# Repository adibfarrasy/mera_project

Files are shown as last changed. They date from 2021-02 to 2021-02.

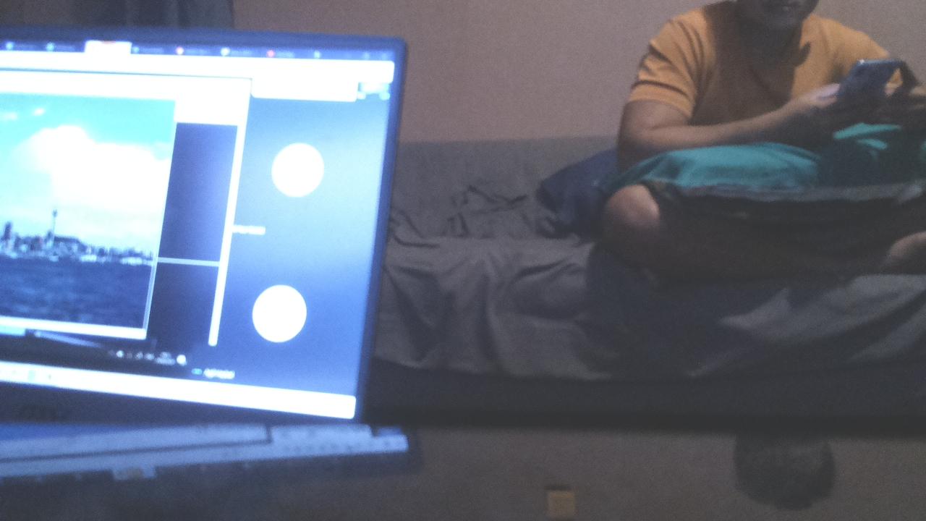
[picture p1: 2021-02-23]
device_firmware/temp_img.jpg

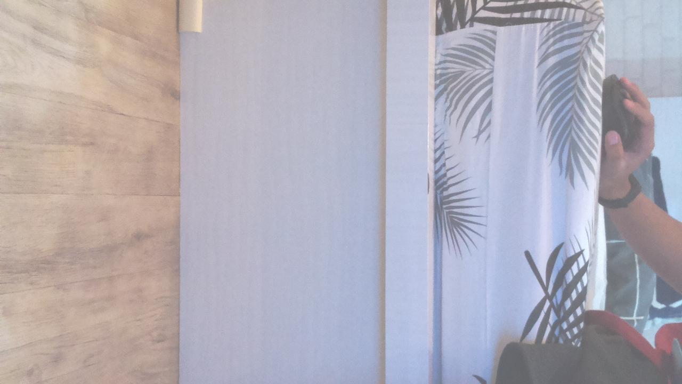
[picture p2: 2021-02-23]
device_firmware/state_of_the_art/temp_img.jpg

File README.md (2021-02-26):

# Mera Project #
My startup documentations. Project initiated in July 2020.

## My Role ##
- Mechanical Designer
- Electrical Designer
- Software Engineer
- Test Engineer
- Manufacturing Engineer
- Product Owner

## My Key Contributions ##
- Project Management
- Concept & Feature Generation
- Bill of Materials
- Scalable Hardware Design
- Scalable Firmware Design
- Prototyping & Testing
- Operations Planning
- QC Planning

## Project Summary ##
Mera planned to use Raspberry Pi SBC to enable KPI-tracking Digital Out Of Home (DOOH) media players e.g. media reach, media impression, audience gender, etc.\
The computer vision feature is deployed in an AWS, and the device serves to send video and camera metadata to the AWS database to be inferred by the deployed model.

## What's Inside ##
- `device_firmwares` directory contains the device codes that I developed for the Mera device.\
- `project_management` directory contains documents in the first few stages of the product lifecycle e.g. product requirements, Bill of Materials, FMEA, etc.\
- `operations_management` directory contains miscellaneous documents for startup operation purposes

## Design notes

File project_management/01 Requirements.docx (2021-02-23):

## MERA Lift Requirements

### SHALL - Commercial Claims

Note: these requirements exist to satisfy the needs of our clients, and to be used for our product's advertisement.

It is strongly preferred for these requirements to have objective quantitative measures such that they can hold up in court as a compelling evidence. As a start, all the requirements will be validated by in-house testing.

AI shall determine people’s gender with acceptable accuracy.

Min. spec: 85.0%

Max. spec: 99.7%

Validation plan: Test Plan LCC-01: Gender Classification

Validation result: Test Report LCC-01: Gender Classification

Target validated: Q3 2020

AI shall determine ads Reach with acceptable accuracy.

Min spec: 85.0%

Max. spec: 99.7%

Validation plan: Test Plan LCC-02: Reach Classification

Validation result: Test Report LCC-02: Reach Classification

Target validated: Q3 2020

AI shall determine ads Impression with acceptable accuracy.

Min spec: 85.0%

Max. spec: 99.7%

Validation plan: Test Plan LCC-03: Impression Classification

Validation result: Test Report LCC-03: Impression Classification

Target validated: Q3 2020

AI shall determine people’s age with acceptable accuracy.

Min spec: 85.0%

Max. spec: 99.7%

Validation plan: Test Plan LCC-04: Age Classification

Validation result: Test Report LCC-04: Age Classification

Target validated: Q3 2020

Device shall update to server frequently.

Min spec: 1 update/hour

Max. spec: 1 update/minute

Validation plan: Test Plan LCC-05: Connection Reliability

Validation result: Test Report LCC-05: Connection Reliability

Target validated: Q3 2020

Device shall detect which advertisement is displayed with acceptable accuracy.

Min spec: 95.0%

Max. spec: 99.7%

Validation plan: Test Plan LCC-06: Advertisement Detection

Validation result: Test Report LCC-06: Advertisement Detection

Target validated: Q3 2020

Device shall be secure in handling data.

Min spec: NA

Max. spec: NA

Validation plan: Data Ethics Guideline

Validation result: Peer Review with Core Mera Team

Target validated: Q3 2020

Device shall have a long runtime.

Min spec: 2160 hours of continuous operation

Max. spec: 9999 hours of continuous operation (outliers to be force-retired)

Validation plan: Test Plan LCC-07: Device Life

Validation result: Test Report LCC-07: Device Life

Target validated: Q3 2020

### MUST - User Safety and Comfort

Note: these requirements exist to protect all relevant stakeholders involved in the operation of the tangible aspect of our product.

It is strongly preferred for these requirements to have objective quantitative measures such that they can hold up in court as a compelling evidence. As a start, all the requirements will be validated by in-house testing.

Device must be quiet.

Min spec: 0dB at 1m distance

Max. spec: 62dB at 1m distance (-10dB from ambient noise)

Validation plan: Test Plan LUC-01: Device Acoustics

Validation result: Test Report LUC-01: Device Acoustics

Target validated: Q3 2020

Device electronics must not emit excess heat.

Min spec: 25 degrees Celsius @24 hr operation time

Max. spec: 80 degrees Celsius @24 hr operation time

Validation plan: Test Plan LUC-02: Device Temperature

Validation result: Test Report LUC-02: Device Temperature

Target validated: Q3 2020

Device must not emit toxic materials.

Min spec: NA

Max. spec: NA

Validation plan: Material Database

Validation result: Peer Review with Core Mera Team

Target validated: Q3 2020

Device must have abnormal case detections and shutdown procedures.

Min spec: NA

Max. spec: NA

Validation plan: Disruption Handling Database

Validation result: Peer Review with Core Mera Team

Target validated: Q4 2020

Device must be electrically insulated.

Min spec: -

Max. spec: no leakage

Validation plan: Test Plan LUC-03: Device Electrical Insulation

Validation result: Test Report LUC-03: Device Electrical Insulation

Target validated: Q4 2020

Device must be firmly mounted on the wall.

Min spec: 20N (approx. 10x device weight)

Max. spec: -

Validation plan: Test Plan LUC-04: Device Mounting

Validation result: Test Report LUC-04: Device Mounting

Target validated: Q4 2020

### SHOULD - Design Excellence

Note: these requirements exist to ensure we deliver the best product in the market, and to ensure a pleasant product experience to the relevant stakeholders in the fabrication, shipment, storage, installation, operation, and disposal of the tangible aspect of our product.

Dashboard should update frequently.

Min spec: 1 update/hour

Max. spec: 1 update/minute

Validation plan: Test Plan LDE-01: Dashboard Responsiveness

Validation result: Test Report LDE-01: Dashboard Responsiveness

Target validated: Q4 2020

Device should be aesthetically pleasing.

Min spec: NA

Max. spec: NA

Validation plan: Product Design Guideline

Validation result: Peer Review with Core Mera Team

Target validated: Q4 2020

Device should clearly show Mera brand.

Min spec: NA

Max. spec: NA

Validation plan: Product Design Guideline

Validation result: Peer Review with Core Mera Team

Target validated: Q4 2020

Device should be resilient to tampering.

Min spec: NA

Max. spec: NA

Validation plan: Product Design Guideline

Validation result: Peer Review with Core Mera Team

Target validated: Q4 2020

Device should be minimalistic.

Min spec: NA

Max. spec: NA

Validation plan: Product Design Guideline

Validation result: Peer Review with Core Mera Team

Target validated: Q4 2020

Device should be operable in dynamic light conditions.

Min spec: 100 Lux

Max. spec: 10,000 Lux

Validation plan: Test Plan LDE-02: Camera Sensitivity

Validation result: Test Report LDE-02: Camera Sensitivity

Target validated: Q4 2020

AI should determine stay duration of people in the lift with acceptable accuracy.

Min spec: 85.0%

Max. spec: 99.7%

Validation plan: Test Plan LDE-03: Duration Detection

Validation result: Test Report LDE-03: Duration Detection

Target validated: Q4 2020

Device should be serviceable.

Min spec: NA

Max. spec: NA

Validation plan: Technical Work Instruction

Validation result: Peer Review with Core Mera Team

Target validated: Q4 2020

Dashboard should be aesthetically pleasing.

Min spec: NA

Max. spec: NA

Validation plan: Product Design Guideline

Validation result: Peer Review with Core Mera Team

Target validated: Q4 2020

Dashboard should clearly show Mera brand.

Min spec: NA

Max. spec: NA

Validation plan: Product Design Guideline

Validation result: Peer Review with Core Mera Team

Target validated: Q4 2020

Dashboard should be minimalistic.

Min spec: NA

Max. spec: NA

Validation plan: Product Design Guideline

Validation result: Peer Review with Core Mera Team

Target validated: Q4 2020

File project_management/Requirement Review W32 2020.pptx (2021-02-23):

## Requirement Review

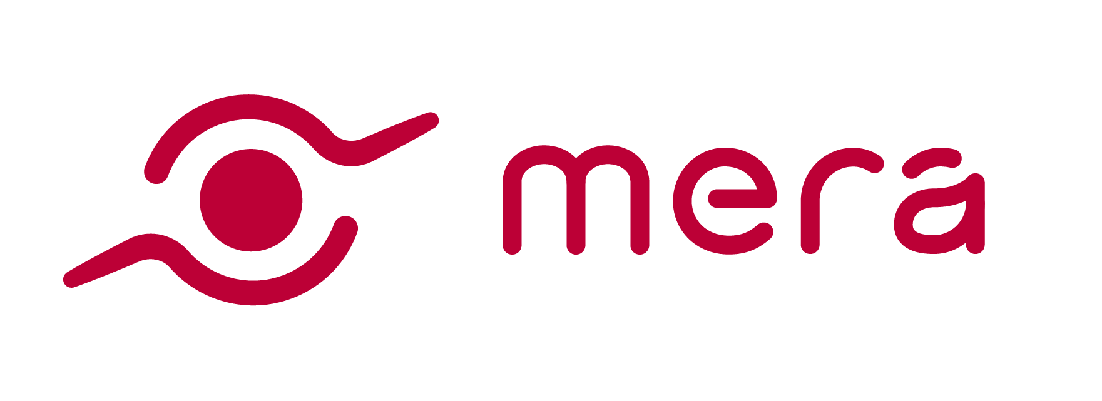
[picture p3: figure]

Author: Adib Farrasy
Date: 08/08/2020

Where we are

SHALL

MUST

SHOULD

0%

0%

0%

completion

completion

completion

Q3 2020 Target: 0%

Q3 2020 Target: 100%

Q3 2020 Target: 50%

## Requirement Review

Agenda #1
Requirement Name: Product should be minimalistic

Agenda #2
Requirement Name: Product should be aesthetically pleasing

Agenda #3
Requirement Name: Product should clearly show Mera brand

## Peer Review

Product should be minimalistic.

Agenda #1

Primary view/ Facade:

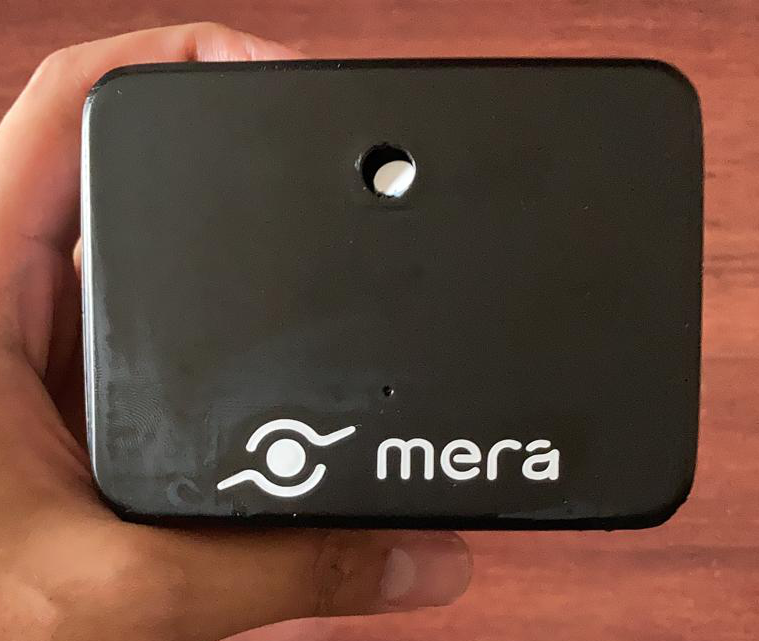
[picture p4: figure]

Result | PASS/ ALLOW / FAIL
Test Resolution | Full Product
Core Team Signoff | <Hilmy/ Agil/ Fatchur>

Secondary views:

Tertiary views:

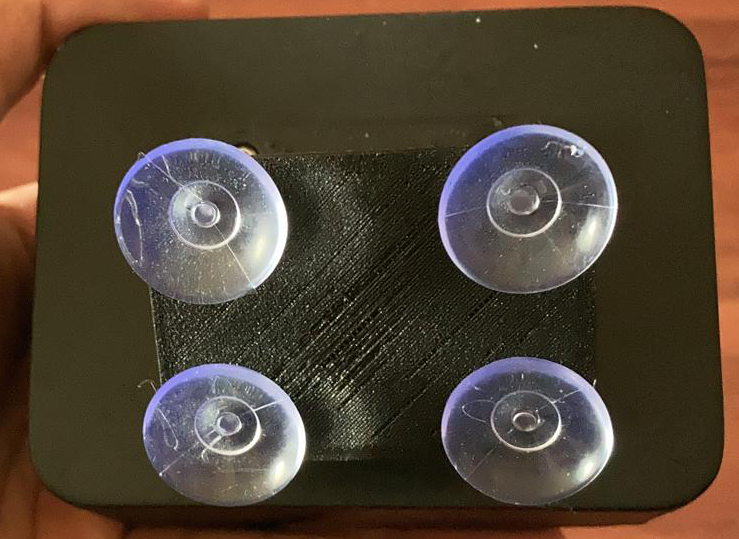
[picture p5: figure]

mounts

Back

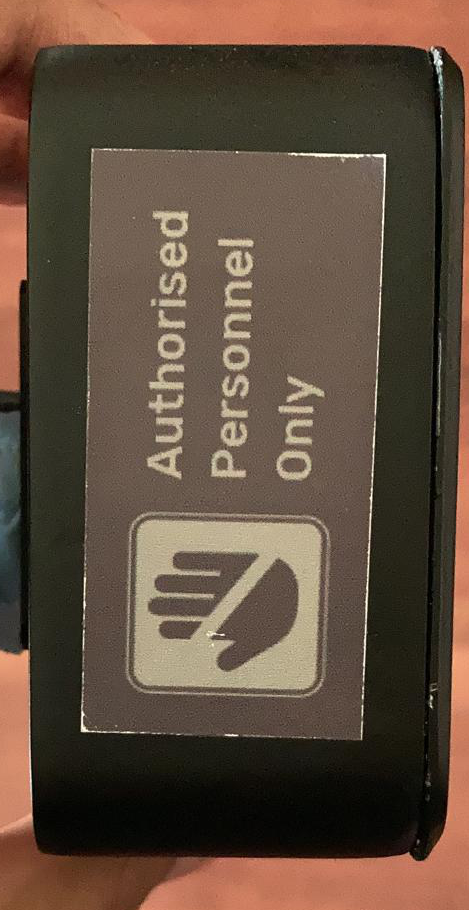
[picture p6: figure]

sticker

Right

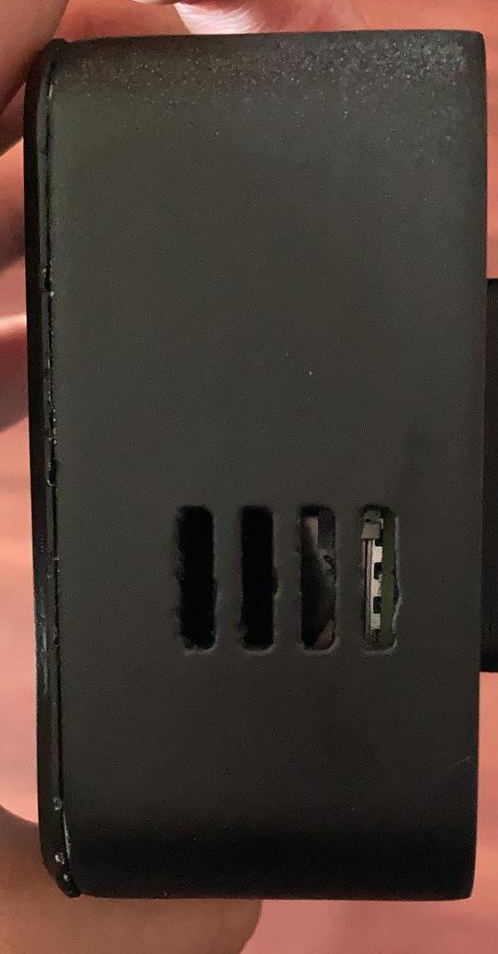
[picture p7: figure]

vent holes

Left

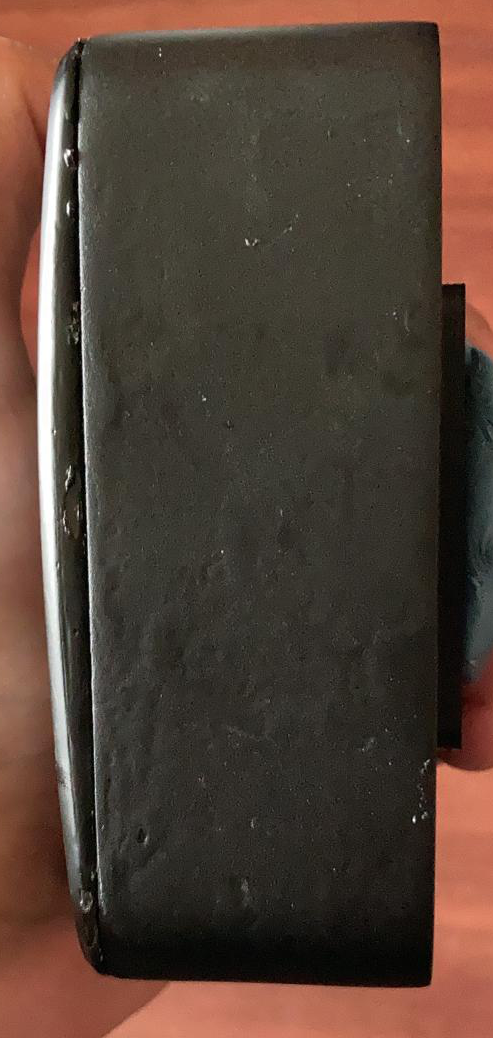
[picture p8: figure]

Bottom

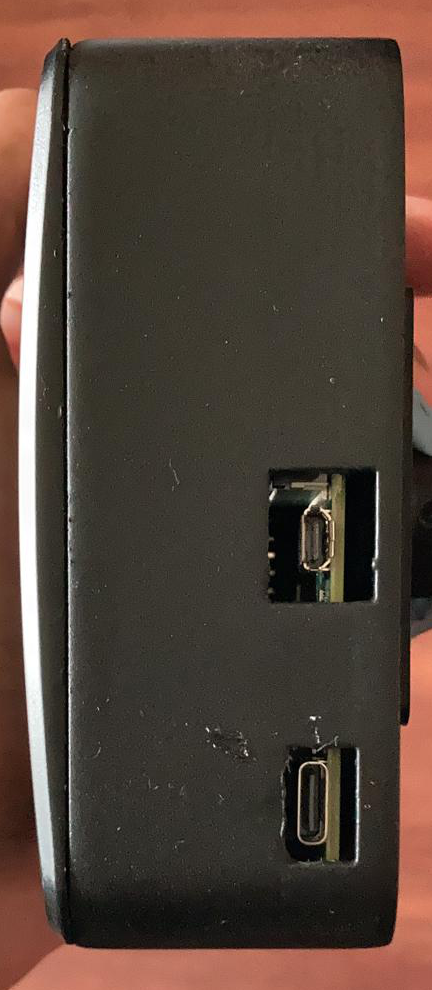
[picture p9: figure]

Cable holes

Top

camera

Indicator light

logo

NEED SIGNOFF
- Quality OK?
- Features OK?
- Minimalism achieved?

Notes: Agil: all OK, need validation of suction cup strength
Hilmy: all OK, change sticker color
Fatchur: all OK

## Peer Review

Product should be aesthetically pleasing.

Agenda #2

Primary view/ Facade:

Device footprint:
100mm x 75mm
40mm thk without mounts, ~88mm thk with mounts.

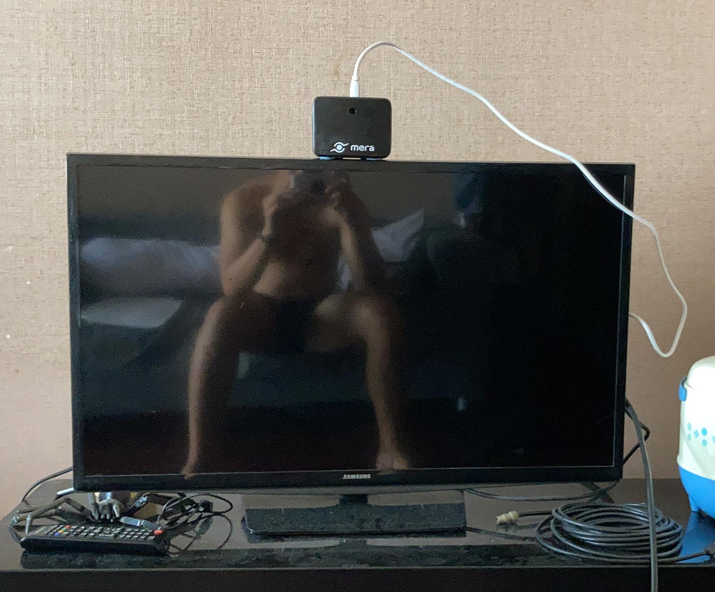
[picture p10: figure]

4.9”

32”

Result | PASS/ ALLOW / FAIL
Test Resolution | Full Product
Core Team Signoff | <Hilmy/ Agil/ Fatchur>

NEED SIGNOFF
- Device size OK?
- Device position OK?
- Visible wires OK?

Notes: Hilmy: size OK, position ALLOW: prefer higher position, visible wires NOT OK
Agil: size OK, position OK, visible wires NOT OK
Fatchur: size OK, positon OK, visible wires NOT OK

TRY L-shaped cable facing back, black color

## Peer Review

Product should clearly show Mera brand.

Agenda #3

Unresized photos:
Taken at eye level, angle adjusted to show device

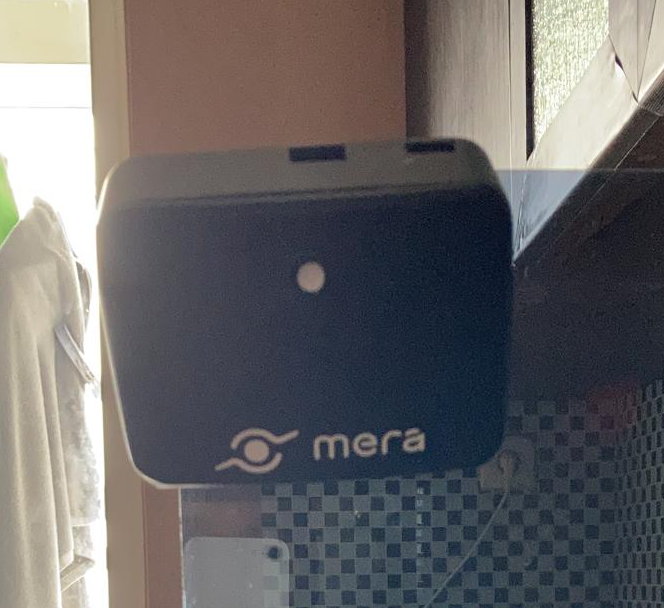
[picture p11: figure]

Device @ eye level

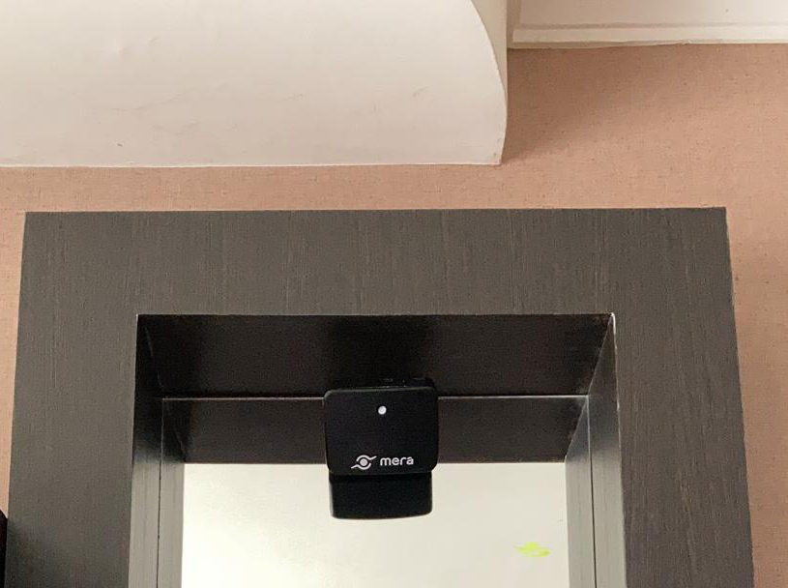
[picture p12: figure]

Device @ ~2.5m height

NEED SIGNOFF
- Logo visibility OK?
- Brand name visibility OK?

Result | PASS/ ALLOW / FAIL
Test Resolution | Full Product
Core Team Signoff | <Hilmy/ Agil/ Fatchur>

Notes: Hilmy: visibility OK, name OK
Agil: visibility OK, name OK
Fatchur: visibility OK, name OK

## Alternative Approach

RISK: Current design may not be aesthetically pleasing.
Addressing wires: use Bluetooth HDMI.
Addressing size: use Pi Zero W (DESIGN OVERHAUL)
Addressing position:
mount to the side nearest to the HDMI port (if using cable)
mount further up to be more discreet?

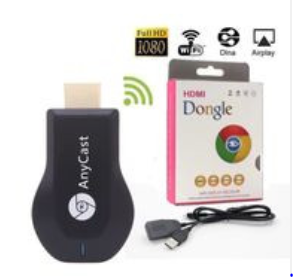
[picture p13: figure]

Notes: Bluetooth HDMI: Compatibility issue? Reliability issue?

## Alternative Approach

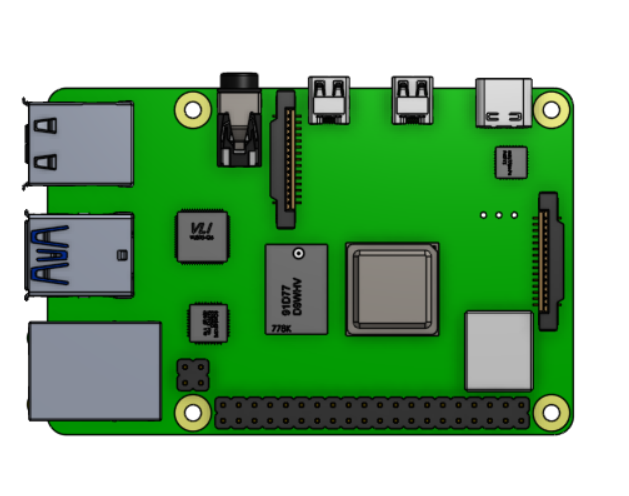
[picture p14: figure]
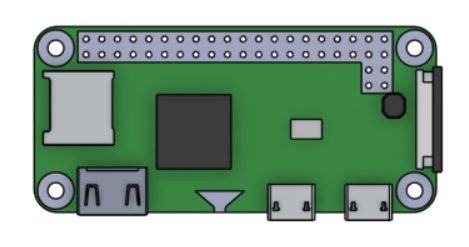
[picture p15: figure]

| Pi Zero W | Pi 4B 2GB
Dimension | 66.0mm x 30.5mm x 5.0mm | 85.6mm × 56.5mm x 18.6mm
Processor | 1.0GHz, single core | 1.5GHz, quad core
RAM | 1GB | 2GB
Cost | US$10 (Rp172.000)/ Rp370.000 Tokopedia | US$35 (Rp520.000)/ Rp 710.000 Tokopedia

## Mera Lift Pi Zero Preview

Primary view/ Facade:

Device footprint:
130*mm x 35mm
40mm thk without mounts, ~88mm thk with mounts.
*length can be shortened up to 80mm

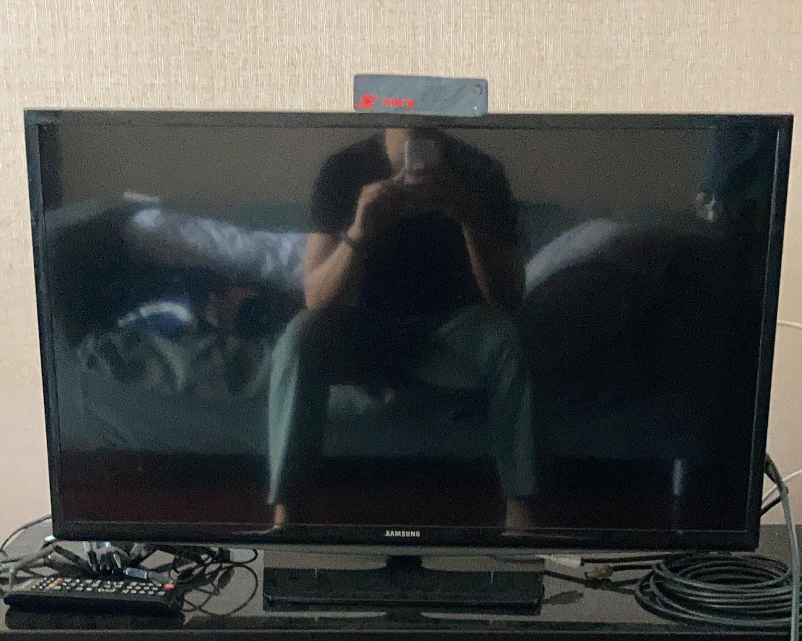
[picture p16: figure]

Orientation Option A
Top of TV
MUST use BT-HDMI

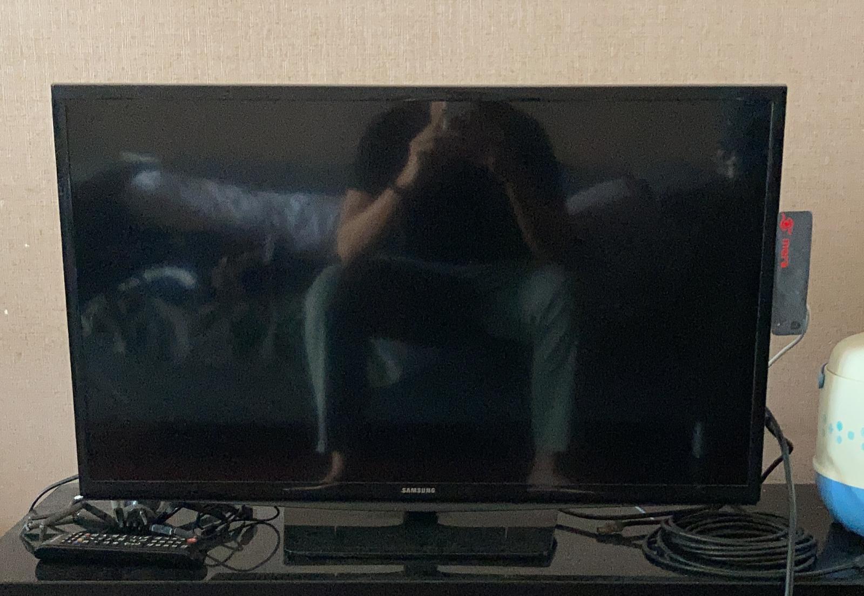
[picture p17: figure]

5.3”

Orientation Option B
Side of TV (nearest to HDMI port)
Don’t need BT-HDMI

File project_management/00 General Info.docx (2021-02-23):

# MERA Lift

MERA Lift project does not include the TV to display the ad. Display devices required will be provided by the contractor, but the video player will be connected to the MERA Lift device for data collection.

Product Visual

### MERA Lift - Isometric View

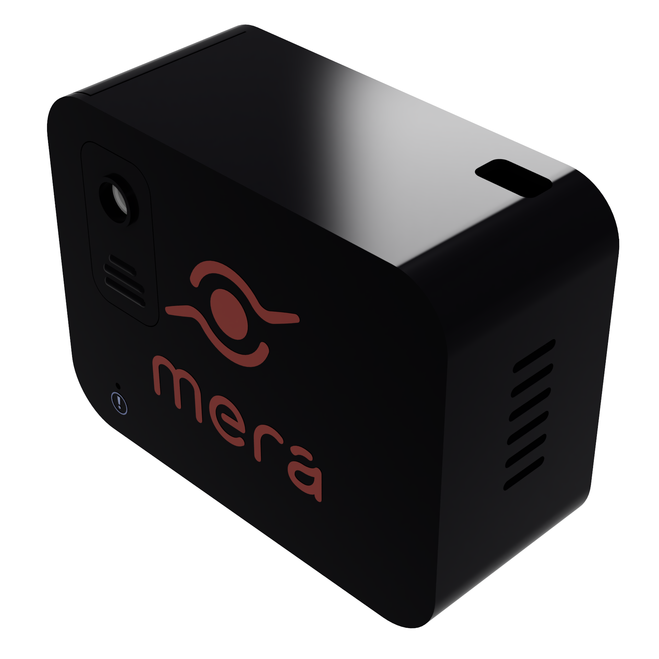
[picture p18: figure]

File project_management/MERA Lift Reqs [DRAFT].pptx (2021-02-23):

## MERA Lift

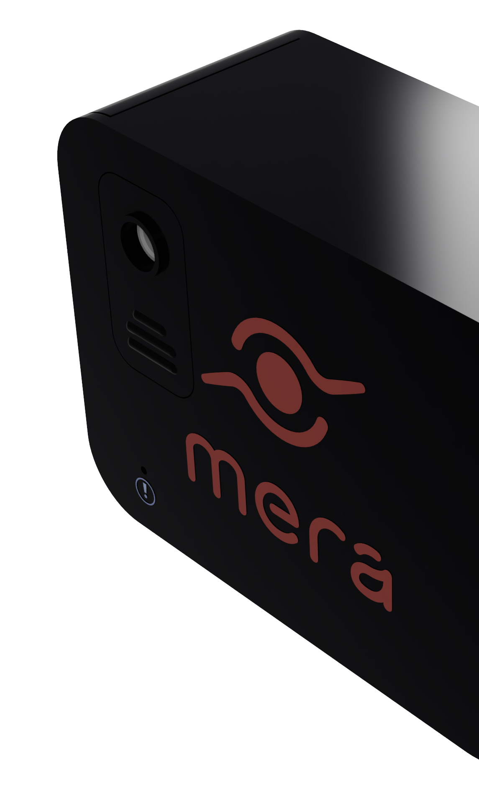
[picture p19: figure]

Requirements

## Commercial Claims

SHALL - Commercial Claims
Product shall determine people’s gender with acceptable accuracy | Product shall update to dashboard frequently | Dashboard shall display Reach based on time and place
Product shall determine ads Reach with acceptable accuracy | Product shall detect which advertisement is displayed | Dashboard shall display Impression based on time and place
Product shall determine ads Impression with acceptable accuracy | Product shall be secure in handling data | Dashboard shall display gender based on time and place
Product shall determine people’s age with acceptable accuracy | Product shall have long run time | Dashboard shall display age based on time and place

## User Safety and Comfort

MUST - User Safety and Comfort
MERA Lift - Product must be quiet in normal and abnormal operations | Product must have abnormal case detections and abnormal shutdown procedure | Product must be electrically insulated in normal and abnormal operations
Product must not emit excess heat in normal and abnormal operations | Data collected must be honestly disclosed with regards to its use | Product must be firmly mounted on the lift wall
Product must not emit toxic materials in normal and abnormal operations | Product must be environmentally friendly

## Design Excellence

SHOULD - Design Excellence
Product should update to server frequently | Dashboard should be aesthetically pleasing | Product should determine stay duration of people in the lift with acceptable accuracy
Product should be aesthetically pleasing | Product design should be minimalistic | Product should be serviceable
Product should clearly show MERA brand | Product device status should be monitored in the dashboard | Dashboard design should be minimalistic
Product should be resilient to lay people tampering | Product should be operable in natural light conditions | Dashboard should be visually displayed in graphs

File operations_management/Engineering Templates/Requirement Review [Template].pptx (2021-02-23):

## Requirement Review


Author: John Doe
Date: DD/MM/YYYY

Where we are

SHALL

MUST

SHOULD

0%

0%

0%

completion

completion

completion

Q3 2020 Target: 0%

Q3 2020 Target: 100%

Q3 2020 Target: 50%

## Requirement Review

Author: John Doe
Date: DD/MM/YYYY

Agenda #1
Requirement Name: Product shall/must/should

Agenda #2
Requirement Name: Product shall/must/should

Agenda #N
Requirement Name: Product shall/must/should...

## Verification Process

Agenda #N

For full document, refer to test report XX-XX
Summarize relevant data here, taken from Test Report.

Result | PASS/ ALLOW / FAIL
Test Resolution | <Part/ Assembly/ Modular/ Full Product>
Core Team Signoff | <Hilmy/ Agil/ Adib>

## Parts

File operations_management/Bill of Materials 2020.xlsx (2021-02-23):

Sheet: Equipment
No | Date | Item | Price | Cur | Qty | Shipping Cost | Total Cost (kIDR) | Rationale | Grand Total (in kIDR)
1 | 2020-05-07 | 3D printer | 787.36 | SGD | 1 | 0 | 8228 | for case prototyping | 8,810.90
2 | 2020-12-07 | soldering kit | 198 | kIDR | 1 | 0 | 198 | for electronics prototyping
3 | 2020-12-07 | caliper | 50 | kIDR | 1 | 0 | 50 | for quality check
4 | 2020-12-07 | glass bed | 149 | kIDR | 1 | 0 | 149 | for case prototyping
5 | 13/7/2020 | blue tack | 21 | kIDR | 1 | 0 | 21 | for case prototyping
6 | 21/7/2020 | M2.5 screws | 1.1 | kIDR | 50 | 0.7 | 55.7 | for case prototyping
7 | 21/7/2020 | super glue | 50 | kIDR | 1 | 10 | 60 | for case prototyping
8 | 21/7/2020 | solder lead | 11.2 | kIDR | 1 | 9 | 20.2 | for electronics prototyping
9 | 21/7/2020 | 5050 LED | 1.4 | kIDR | 10 | 15 | 29 | for electronics prototyping
10 | 29/7/2020 | Amplas Assorted Grits | 2.5 | kIDR | 4 | 5.1 | 15.1 | for case prototyping
11 | 2020-08-08 | Anycast HDMI Dongle | 67.5 | kIDR | 1 | 10 | 77.5 | for electronics prototyping
12 | 2020-04-08 | Cooling Fan 5V 3010 | 62 | kIDR | 1 | 9 | 71 | for electronics prototyping
13 | 13/8/2020 | Dempul Kayu Propan | 28.5 | kIDR | 1 | 9 | 37.5 | for case prototyping
14 | 2020-09-08 | Heatsink Aluminum 8x8x5 | 1.9 | kIDR | 1 | 8.6 | 10.5 | for electronics prototyping
15 | 13/8/2020 | Kabel HDMI to Mini HDMI | 50 | kIDR | 1 | 5 | 55 | for electronics prototyping
16 | 17/8/2020 | Mur M2.5 | 0.4 | kIDR | 50 | 10 | 30 | for electronics prototyping
17 | 2020-11-08 | Raspberry Pi Zero W | 2 | kIDR | 375 | 41.768 | 791.768 | for electronics prototyping
18 | 16/8/2020 | RPi Zero Camera 5MP | 217 | kIDR | 1 | 10 | 227 | for electronics prototyping
19 | 16/8/2020 | SanDisk Ultra MicroSD 32GB | 85.8 | kIDR | 2 | 18 | 189.6 | for electronics prototyping

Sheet: MERA Lift Q3 2020
No | Date | Item | Price | Cur | Qty | Total Cost (kIDR) | Rationale | Grand Total (in kIDR)
1 | 15/6/2020 | Raspberry pi 4B 8GB | 119.99 | SGD | 1 | 1253.8955 | SBC for Adib's protoyping | 5577.15
2 | 15/6/2020 | Micro HDMI to HDMI adapter | 10.71 | SGD | 1 | 111.9195 | Adapter for Adib's protoyping
3 | 15/6/2020 | 15W USB-C UK power plug | 12.50 | SGD | 1 | 130.625 | power plug for Adib's protoyping
4 | 15/6/2020 | 16GB Micro SD Card | 12.86 | SGD | 1 | 134.387 | hard disk for Adib's protoyping
5 | 15/6/2020 | Raspberry pi 4B case | 8.93 | SGD | 1 | 93.3185 | case for Adib's prototyping
6 | 2020-05-05 | Wi-Fi Wireless adapter | 42.00 | kIDR | 1 | 42 | for Fatchur's protoyping
7 | 2020-05-05 | Raspi Camera Module v2 | 439.00 | kIDR | 1 | 439 | for Fatchur's protoyping
8 | 2020-05-05 | Raspberry pi 4B 4GB full kit | 1304.00 | kIDR | 1 | 1304 | for Fatchur's protoyping
9 | 2020-05-05 | Nvidia Jetson Nano Devkit | 2068.00 | kIDR | 1 | 2068 | for Fatchur's protoyping

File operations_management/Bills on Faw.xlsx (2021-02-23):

Date | Item | Price | Qty | Shipping | Total Cost | Rationale | Grand Total (in kIDR)
2020-07-11 | 3d Filament Silk Black Gray 1 kg (https://www.tokopedia.com/xyzgarage/3d-filament-silk-black-gray-1-kg) | 230000 | 1 | 11000 | 241000 | 3d printer filament | 1.724.750,00
2020-07-14 | Studio Mini Box | 41000 | 1 | 5500 | 46500 | product showcasing
2020-07-14 | Rotating Display | 25000 | 1 | 10000 | 35000 | product showcasing
2020-07-14 | Knife Pen | 23500 | 1 | 5500 | 29000 | general purpose
2020-07-14 | Print UV Decal sticker | 130000 | 1 | 0 | 130000 | trying out sticker materials. failed.
2020-07-20 | Cutting Sticker V&J | 20000 | 1 | 13000 | 33000 | cutting sticker for device visual. success.
2020-07-23 | Bahan Filament PLA Printer 3D aneka pilihan warna (https://www.tokopedia.com/voltapro49/bahan-filament-pla-printer-3d-aneka-pilihan-warna) | 186000 | 1 | 15900 | 201900 | new 3d filament supplier
2020-07-26 | Ditton Spray paint | 20000 | 3 | 5500 | 65500 | device coloring
2020-08-01 | Paper Corner-rounder | 49900 | 1 | 5500 | 55400 | general purpose
2020-08-01 | Nail drill grinder | 58800 | 1 | 0 | 58800 | for polishing device
2020-08-03 | Ditton Spray paint | 21000 | 3 | 0 | 63000 | device coloring
2020-08-07 | Lem Rajawali | 15000 | 1 | 5000 | 20000 | for polishing device
2020-08-07 | Bahan Filament PLA Printer 3D aneka pilihan warna (https://www.tokopedia.com/voltapro49/bahan-filament-pla-printer-3d-aneka-pilihan-warna) | 179900 | 1 | 0 | 179900 | 3d printer filament
2020-08-07 | Print Proposal AMG & Clinks v1 | 91900 | 1 | 48000 | 139900 | reading materials for potential media partners
2020-08-07 | Business Card | 27500 | 1 | 0 | 27500 | card to give out to partners/clients/anyone
2020-08-10 | Device hole-cover sticker | 57750 | 1 | 48000 | 105750 | for security measures
2020-08-07 | Print Proposal AMG v2 | 91900 | 1 | 48000 | 139900
2020-08-21 | Cutting Sticker V&J | 60000 | 1 | 0 | 60000 | device visual
2020-08-23 | Print Proposal Clinks v2 | 68700 | 1 | 24000 | 92700

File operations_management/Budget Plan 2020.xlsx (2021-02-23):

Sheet: Equipment
No | Item | Price | Cur | Qty | Total Cost (kIDR) | Rationale | Grand Total (in kIDR)
1 | Soldering station | 35 | USD | 1 | 525 | Electronics prototyping | 12600
2 | Cardboard prototyping tools | 5 | USD | 1 | 75 | Scissor, tape, cutter, glue gun, etc.
3 | 3D printer (Creality Ender 3 clone) | 800 | USD | 1 | 12000 | For prototyping the casing design.

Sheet: MERA Lift Q3 2020
No | Item | Price | Cur | Qty | Total Cost (kIDR) | Rationale | Grand Total (in kIDR)
1 | Raspberry Pi 4 2GB | 709 | kIDR | 1 | 709 | Main SBC | 1450.8
2 | 5V 3A Official RPi adapter | 39.9 | kIDR | 1 | 39.9 | Connect to mains
3 | Camera Module v2 | 430 | kIDR | 1 | 430 | Vision sensor
4 | SanDisk Ultra 32GB | 95 | kIDR | 1 | 95 | Micro SD storage
5 | SMT 5050 LED | 1.4 | kIDR | 1 | 1.4 | Light indicator
6 | 30x30 5V fan | 30 | kIDR | 1 | 30 | Cooling solution
7 | Prototyping consumables | 10 | kIDR | 1 | 10 | Headers, wires, solder lead, screws, nuts, etc
8 | 3D printer filament | 40 | kIDR | 1 | 40 | For 3D printing casing.
9 | suction cups | 0.5 | kIDR | 3 | 1.5 | for mounting
10 | HDMI cable | 74 | kIDR | 1 | 74 | for TV
11 | logo sticker | 10 | kIDR | 1 | 10 | for protoype visual
12 | warning sticker | 10 | kIDR | 1 | 10 | for protoype visual

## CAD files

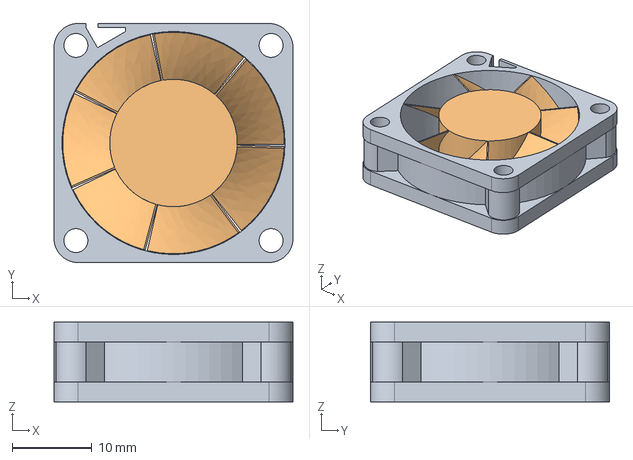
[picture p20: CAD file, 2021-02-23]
operations_management/Bought-out Part Models/30mm_axial_fan.step
30.0 x 30.0 x 10.0 mm

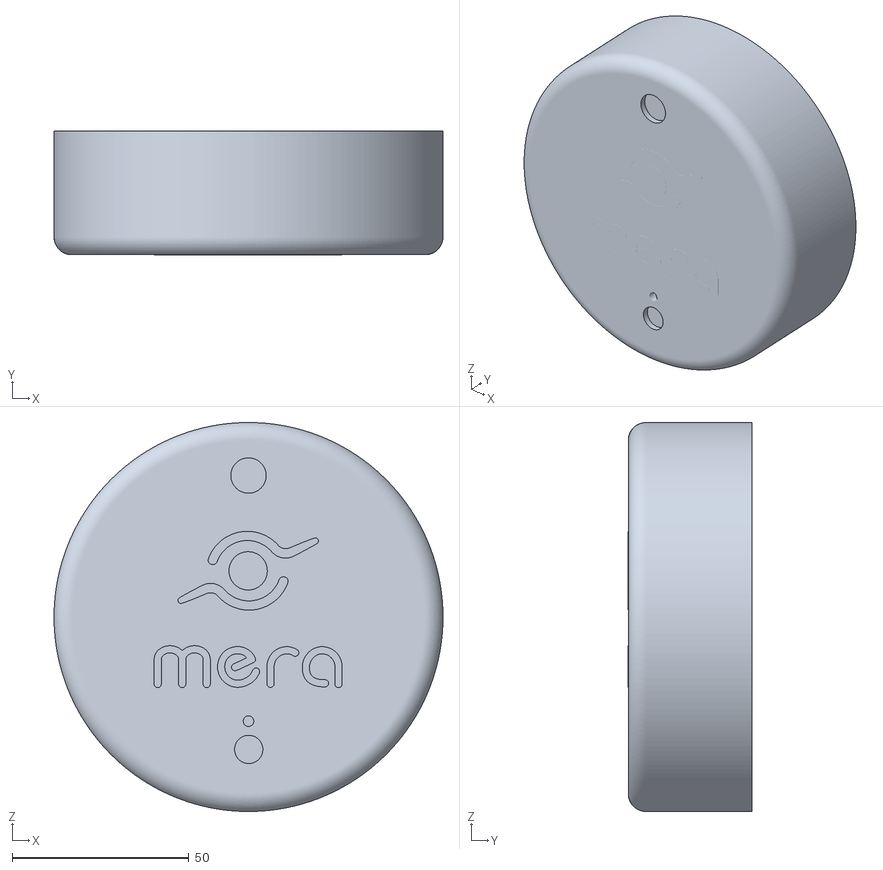
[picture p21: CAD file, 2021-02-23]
project_management/Case Design/B.stl
110.0 x 35.1 x 110.0

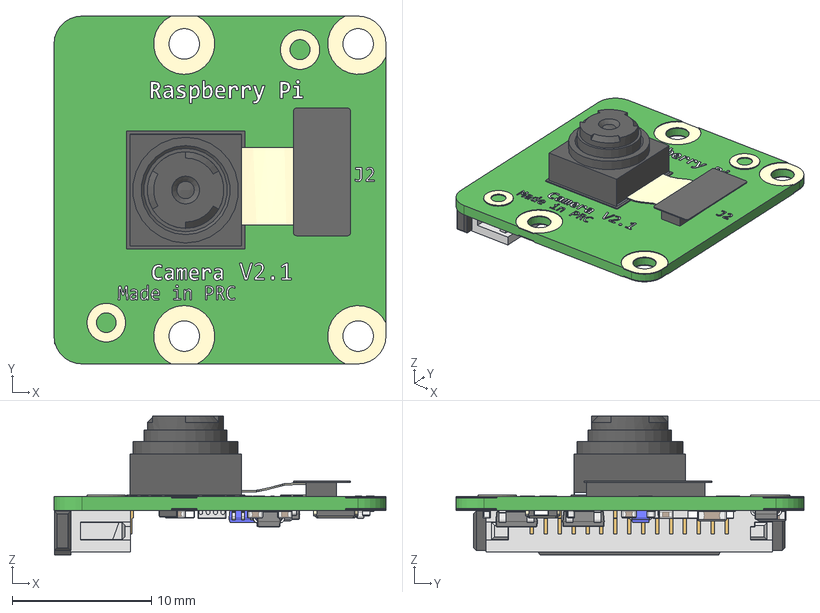
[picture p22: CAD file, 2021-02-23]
operations_management/Bought-out Part Models/RspCameraMia.stp
23.9 x 25.0 x 9.96 mm
PicameraPCB
OVA5647_Housing
OVA5647_Lens_FOV
ribbon_cam
CCD
CAPC-0805-T0.75-BN x 2
CAPC-0402-T0.55-BN x 10
RESC-0402 x 3
RESC-0603 x 2
RESC-1210
c-1-1734248-5-e-raspberry_display
SOT23-5 x 3
KX7 SMD Quartz Crystal Resonator 3.2x2.5mm
c6aaa
4pin_smd x 3

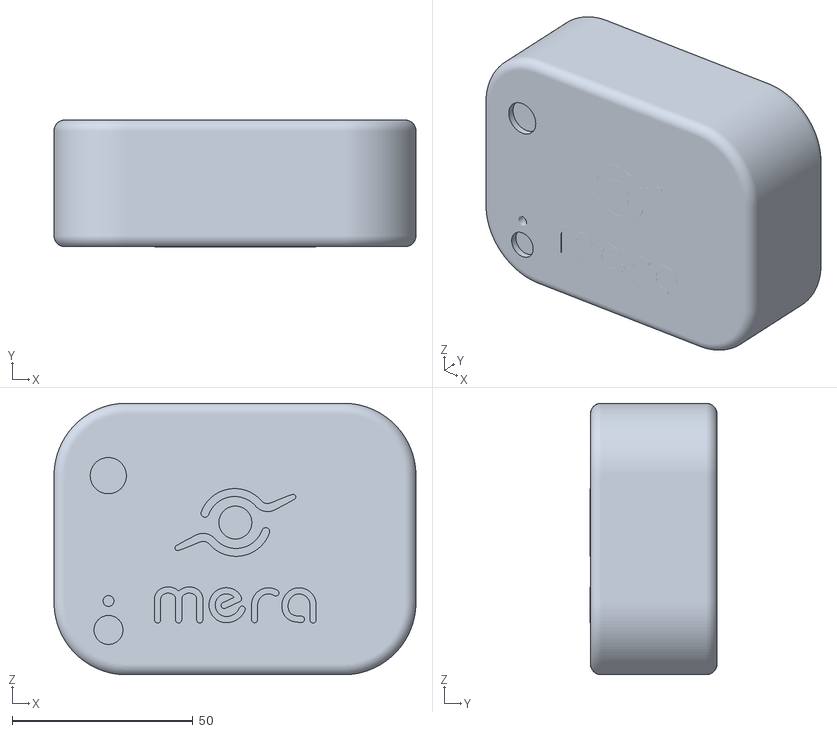
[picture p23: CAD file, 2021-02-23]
project_management/Case Design/D.stl
100.0 x 35.1 x 75.0

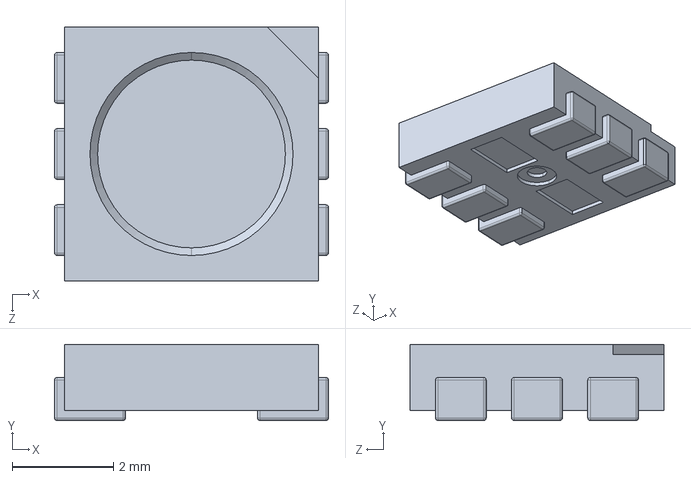
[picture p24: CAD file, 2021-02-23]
operations_management/Bought-out Part Models/led5050.STEP
5.40 x 1.50 x 5.00 mm

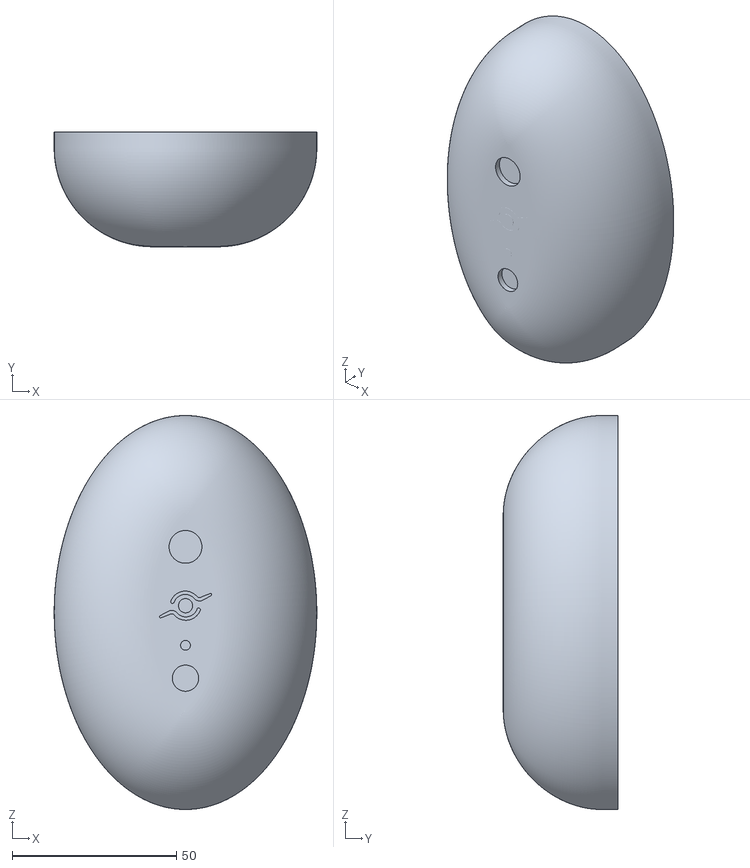
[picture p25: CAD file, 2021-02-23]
project_management/Case Design/A.stl
80.0 x 35.1 x 120.0

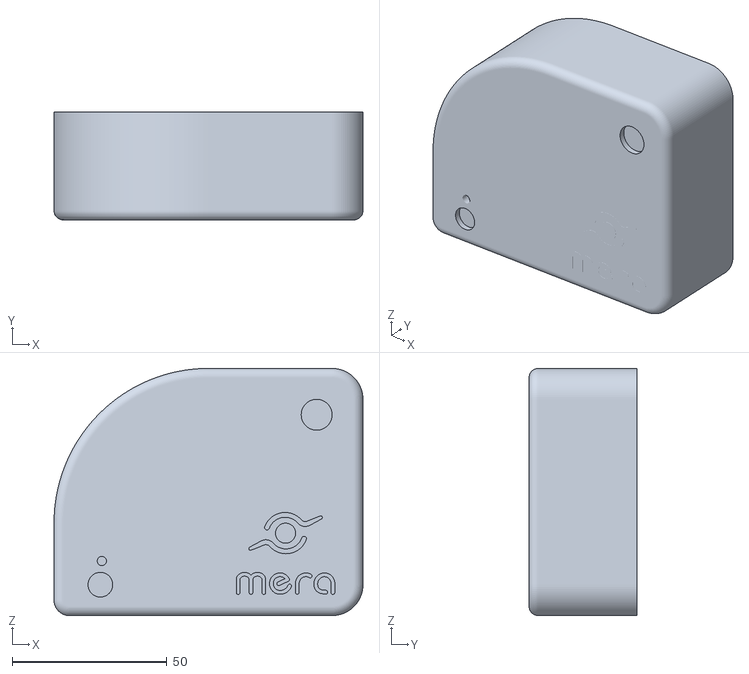
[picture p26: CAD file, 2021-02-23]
project_management/Case Design/C.stl
100.0 x 35.1 x 80.0

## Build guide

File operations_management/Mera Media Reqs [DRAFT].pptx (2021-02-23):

## Mera Media

Hardware Requirements

## Commercial Claims

SHALL - Commercial Claims
Product shall determine people’s gender with acceptable accuracy | Product shall update to backend frequently | Product shall display high resolution content
Product shall determine media Reach with acceptable accuracy | Product shall detect which media is playing near-real time | Product shall play audio
Product shall determine media Impression with acceptable accuracy | Product shall be secure in handling data
Product shall determine people’s age with acceptable accuracy | Product shall have long run time (set-and-forget)

## User Safety and Comfort

MUST - User Safety and Comfort
Product must be quiet in normal and abnormal operations (except the media sound) | Product must have abnormal case detections and abnormal shutdown procedure
Product must not emit excess heat in normal and abnormal operations | Product must be firmly mounted on in the premise
Product must not emit toxic materials in normal and abnormal operations | Product must be electrically insulated in normal and abnormal operations
Product must be environmentally friendly

## Design Excellence

SHOULD - Design Excellence
Product should update to backend frequently | Product should be serviceable
Product should be aesthetically pleasing | Product design should be minimalistic
Product should clearly show Mera brand | Product should determine stay duration of people in the lift with acceptable accuracy
Product should be resilient to lay people tampering | Product should be operable in natural light conditions

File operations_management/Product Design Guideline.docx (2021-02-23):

# Product Design Guideline

Device

<TBD>

Dashboard

<TBD>

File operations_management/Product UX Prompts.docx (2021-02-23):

PRODUCT JOURNEY PROMPT CHART

consists of Environment, Materials, User Interaction, and User Profile

Environment 1. How might the environment affect the product? 2. How might the product affect the environment? | Atmospheric conditions | Attitude/ pressure
| | Humidity
| | Gas composition
| | Pollution
| | Air temperature
| Acoustics | Noise
| | Vibrations
| Power supply type | Mains frequency
| | Plug type
| | Accessibility to live parts
| | Mains voltage & current
| Radiation | Electromagnetic fields (EMI)
| | Sunlight (UV)
| | Visible light
| | Thermal radiation (infrared)
| Operation environments | Building type
| | Country regulations
| | Indoor or outdoor
| Contact surfaces | Dry/ damp
| | Slippery/ grippy
| | Smooth/ bumpy
| | Hard/ soft
| | Abrasive surface
| | Contact temperature
| Transportation environment | Temperature
| | Humidity
| | Attitude/ pressure
| Storage environment | Temperature
| | Humidity
| | Attitude/ pressure
Materials 1. What materials might come into contact with the product? 2. What materials can the product emit? | Intended Interactions | User interface e.g. buttons
| | Pick and place
| | Fastening
| | Cleaning product
| | Product maintenance
| Material subjects | Animals
| | Human
| | Food
| | Synthetics
| | Air-borne
| | Water-borne
| Hazardous materials | Abrasive surfaces
| | Volatile/ flammable
| | Corrosive
| Unintended interactions | Ingress
| | Contaminants
| | Unexpected cleaning products
| | Unexpected replacement parts
| Material failures | Freezing/ jamming
| | Change in color/ translucency
| | Material wear/ thinning
| | Cracking/ fracturing
| | Clogging
| | Water absorption
| Emissions | Smells
| | Liquid
| | Dust and debris
| Material properties | Case durability
| | Rigidity/ flexibility
| | Waterproof/ absorbent
| | Magnetic
| | Static
| | Conductive/ insulating
User Interaction 1. How is the product supposed to be used? 2. What are the possible uses of the product? | Transport | Handling in freight
| | Hand-carry the product
| Before use | Packaging
| | Unboxing
| | Installing product
| During use | Principal use
| | Connection with Internet/ other device(s)
| | Foreseeable misuse
| | Abuse/ abnormal use
| | Use alongside other product(s)
| | Hacks
| Maintenance | Cleaning
| | Replace parts/ repair
| | System reboot
| After use | Disposal
| | Recycle components
| | Reuse components
| Power use | Power continuously/ short runtime
| | Mains/ battery powered
User Profile 1. How might the product accommodate people's wants and needs? 2. How might the product be interpreted/ misinterpreted? | Active users | Gender
| | Age
| | Relationship status
| Individual factors | Hand size
| | Left/ right handedness
| | Strength
| | Body weight
| | Height
| Special needs | Elderly
| | Infants
| | Handicapped
| Cultural beliefs | Religion
| | Traditional customs
| | Conservativeness/ progressiveness
| | Crowd behavior
| Preferences & expectations | Product’s quality feel perception
| | Audio-visual cues
| | Product capability e.g. works well, hassle-free
| | Positive/ negative associations
| | Brand perception e.g. luxury? durable? good service? “just another startup”?
| Understanding | Technical knowledge
| | Industry knowledge
| Unexpected interactions | Mistakes
| | Instructions ignored
| | Improvisation
| | Subjected to impact
| | Poor treatment
| | Product causes accident
| Servicing | Professional
| | Product owner

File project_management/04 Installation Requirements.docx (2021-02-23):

## Installation Requirements

### Requirements to Contractors

To ensure that the MERA device can work as intended, Contractors need to provide these facilities:

1. A dedicated Wi-Fi network with WPA2 security.
2. A dedicated wireless router NOT further than 5m away from the MERA device.
3. A power plug (rated 250V) NOT further than 1m away from the MERA device.

It is the responsibility of the Contractors to check that the requirements are met and contact the MERA team before installation. A representative from the Contractor’s side must be present to assist MERA Technicians during device installation and troubleshooting.

### Requirements to MERA Technicians

#### Hiring

The technicians must be:

1. >18 years old.
2. Graduated from High School.
3. Good IT skill (familiarity with computers, connecting to Wi-Fi, web browsing, installing/uninstalling softwares).
4. Basic understanding of electrical component installation (checking device condition, checking connections of device peripherals e.g. fans, LEDs, and micro SD cards).

Among other things, be detail-oriented and possess good communication skills.

#### Operational

MERA Technicians are responsible for:

1. Installing the device
2. Troubleshooting electrical/ Internet issues on the device
3. Retrieving faulty device
4. Reporting on his duty to the MERA core team in a timely manner

Any of the technician’s responsibility on-site must be supported by the Contractor’s representative.

### Requirements for Clients

To ensure that the MERA can display the Clients’ ads, Clients’ must ensure:

1. Advertisement videos are in the correct format as required.
2. Advertisement videos sent in to the MERA Team prior to installation.

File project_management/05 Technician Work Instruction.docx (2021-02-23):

## Technician Work Instruction

### First Installation

Mounting?

Wire-routing?

Adjusting the view?

Connecting to network?

We need client to install modem nearby (case-by-case assessment)

We need client to setup dedicated wi-fi (optional)

### Repair

Repair vs replace?

customer pay/ free?

warranty policy?

### Replace

How does the software handle this?

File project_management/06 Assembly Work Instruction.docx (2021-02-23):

## Assembly Work Instruction

### Bill of Materials

#### Components

Part Name | Qty | Image | Remarks
Front Cover | 1 | | 3Dprinted
Chassis | 1 | | 3Dprinted
LED Holder | 1 | | 3Dprinted
Device Mount | 1 | TBD | 3Dprinted
Wall Mount | 1 | TBD | 3Dprinted
Joint Screw | 1 | TBD | 3Dprinted
Joint Nut | 1 | TBD | 3Dprinted
Raspberry Pi 4 16GB RAM | 1 | | Bought-out
Pre-flashed 32GB MicroSD Card | 1 | | Bought-out, modified
Pi Camera Module v2 | 1 | | Bought-out
SMD WS2812B LED | 1 | | Bought-out
5V 3010 Cooling Fan | 1 | | Bought-out
150mm MF Jumper Wire | 3 | | Bought-out
150mm FF Jumper Wire | 1 | | Bought-out
M2.5x6 screws | 7 | | Bought-out

#### Equipment and Consumables

Part Name | Qty | Image | Remarks
Hand Drill | 1 | | Equipment
Hand Drill Cone Attachment | 1 | | Consumable
Soldering Kit | 1 | | Equipment
Solder Lead | 1 | | Consumable
Electrical Tape | 1 | | Consumable
Pen Knife | 1 | | Equipment
Cutting Pliers | 1 | | Equipment
Spray Paint - Black Doff | 1 | | Consumable
Wood Filler | 1 | | Consumable
Sandpaper 240 grit | 1 | | Consumable
Sandpaper 500 grit | 1 | | Consumable
Sandpaper 1000 grit | 1 | | Consumable
Microfiber Towel | 1 | | Equipment
Toothpick | 1 | | Consumable
Hex Allen Key for M2.5 | 1 | | Equipment
TV with HDMI plug | 1 | | Equipment

### A. Preparing the 3Dprinted Parts

#### 1. Post-Processing of Blemishes

Required Equipment and Consumables:

Cutting Pliers, Hand Drill, Hand Drill Cone Attachment.

A. Clean up supports on the inside of Front Cover and Chassis parts

<insert image here>

B. Sand away corner radius imperfections at the bottom corners of front cover

<insert image here>

C. Deburr all vent holes on Chassis

<insert image here>

D. Deburr camera hole on Front Cover

<insert image here>

#### 2. Painting

Note: This step applies for Front Cover and Chassis only.

Required Equipment and Consumables:

Wood Filler, Sandpapers 240, 500, and 1000 grits, Spray Paint - Black Doff, Microfiber Towel.

1. Apply wood filler on blemishes.

<insert image here>

2. Apply excess wood filler on surfaces (facade on Front Cover, all outer faces on Chassis).

<insert image here>

3. Sand with 240 grit + water for 2 minutes.

<insert image here>

4. Wait for 10 minutes.

<insert image here>

5. Dry sand with 500 grit for 2 minutes.

<insert image here>

6. Dry sand with 1000 grit for 2 minutes.

<insert image here>

7. Clean part with dry microfiber cloth.

<insert image here>

8. Spray paint with any color, wait 20 minutes*

<insert image here>

9. repeat steps 5-8 for 2 more times.
10. Wait 24 hour for the last coat of paint to dry.

#### 3. Post-Painting

Note: This step applies for Front Cover and Chassis only.

Required Equipment and Consumables:

Hand Drill, Hand Drill Cone Attachment, Toothpick.

1. Smoothen the edges of the camera hole.

<insert image here>

2. Poke open the paint/ filler in the LED hole.

<insert image here>

### B. Preparing the Electronics

#### 1. Soldering Cooling Fan

Required Equipment and Consumables:

Pen Knife, Soldering Kit, Solder Lead, 150mm FF Jumper Wires.

1. Cut the plastic terminal.

<insert image here>

2. Strip the plastic insulation to expose ~10mm of copper wires for each red and black wire.

<insert image here>

3. Cut 2pcs of ~20mm of female jumper wires.

<insert image here>

4. Strip the plastic insulation to expose ~10mm of copper wires for each jumper wire (2pcs).

<insert image here>

5. Solder the exposed copper from the fan wires to the exposed copper from jumper wires.

<insert image here>

6. The soldered red wire and jumper are the "Fan live wire". The soldered black wire and jumper are the "Fan ground wire".

<insert image here>

7. Cover the exposed copper + solder lead with ~10mm electrical tape.

<insert image here>

#### 2. Soldering LED

Required Equipment and Consumables:

Pen Knife, Soldering Kit, Solder Lead, 150mm MF Jumper Wires x3.

1. Cut 3pcs of ~150mm of female jumper wires.

<insert image here>

2. Strip the plastic insulation to expose ~10mm of copper wires for each jumper wire (3pcs).

<insert image here>

3. Solder jumper wire #1 to the ground terminal of LED (marked with triangle cutout in front). This is the "LED ground wire".

<insert image here>

4. Solder jumper wire #2 to the live terminal of LED (diagonal to the ground terminal). This is the "LED live wire".

<insert image here>

5. Solder jumper wire #3 to the signal terminal of LED (from front view, above the ground terminal and to the right of the live terminal. Note: there is only one correct orientation). This is the "LED signal wire".

<insert image here>

### C. Assembly

#### 1. Enclosing Raspberry Pi

Required Equipment and Consumables:

Hex Allen Key for M2.5.

1. Insert the Pi Camera Module v2 into the designated slot on Raspberry Pi 4.

<insert image here>

2. Insert Raspberry Pi 4 into Chassis.

<insert image here>

3. Fix the Raspberry Pi with 2x M2.5 screws.

<insert image here>

#### 2. Assembling Cooling Fan

Required Equipment and Consumables:

NA.

1. Connect the "Fan live wire" to the 3v3 power port of Raspberry Pi 4 (numbered bubble #1, see Appendix A).

<insert image here>

2. Connect the "Fan ground wire" to the Ground port of Raspberry Pi 4 (numbered bubble #6, see Appendix A).

<insert image here>

3. Assemble the fan to the Chassis in its designated slot.

<insert image here>

#### 3. Assembling LED

Required Equipment and Consumables:

Hex Allen Key for M2.5.

1. Connect the "LED live wire" to the 5V power port of Raspberry Pi 4 (numbered bubble #2, see Appendix A).

<insert image here>

2. Connect the "LED signal wire" to the GPIO 18(PCM_CLK) port of Raspberry Pi 4 (numbered bubble #12, see Appendix A).

<insert image here>

3. Connect the "LED ground wire" to the Ground port of Raspberry Pi 4 (numbered bubble #14, see Appendix A).

<insert image here>

4. Gently place the LED such that it aligns with the LED hole on the front cover.

<insert image here>

5. Secure the LED by tightening the M2.5 screw of the LED holder to the designated screw hole using M2.5 allen key. Ensure the LED is firmly held by the holder (no rattle, LED cannot rotate).

<insert image here>

#### 4. Assembling Front Cover

Required Equipment and Consumables:

NA.

1. Assemble the Pi Camera Module v2 into its designated location.

<insert image here>

2. Assemble the Front Cover to the Chassis.

<insert image here>

#### 5. Assembling Mounting Parts

Required Equipment and Consumables:

Hex Allen Key for M2.5.

1. Screw 4pcs of M2.5 screws to fix the Device Mount and Chassis together.

<insert image here>

2. Insert Nanogel to the Wall Mount.

<insert image here>

3. Assemble Device Mount to the Wall Mount.

<insert image here>

4. Adjust the angle of the Device Mount when necessary, then fix the position by tightening the Joint Screw to the Joint Nut.

#### 6. Final Check and Test

1. Plug the micro-HDMI end of the HDMI cable to the micro-HDMI slot on the device.

<insert image here>

2. Plug the HDMI end of the HDMi cable to a TV.

<insert image here>

3. Plug the power cable to the power slot on the device.

<insert image here>

4. Turn on the TV and device.

<insert image here>

5. Once the display is up, execute the “run.sh” file on the Desktop interface.

<insert image here>

6. Check if LED, Cooling Fan and TV display are running smoothly and expectedly.

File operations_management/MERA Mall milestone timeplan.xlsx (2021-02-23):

Milestones |  | Remarks | Q2 2020 | Q3 2020 | Q4 2020 | Q1 2021 | Q2 2021 | Q3 2021 | Q4 2021 | Q1 2022 | Q2 2022
Phase 1: Business | Product requirements defined
 | Intial investor funding secured
 | prototype production cost
 | test cost
 | operational cost (if any)
 | FMEA defined
 | 0th MVP produced | initial technology solution demonstrated (object classification)
Phase 2: R&D | Engineering specifications defined
 | hardware engineering specs defined
 | software engineering specs defined
 | Test methods defined
 | Get test equipment (for hardware eng)
 | Setup tests
 | BUILD AND TEST | iterative, to have regular updates
 | 1st MVP produced | all high risk FMEAs closed, all SHALL+MUST requirements met
Phase 3: Scaling | Bill of Materials released
 | part requirements and QC defined
 | part and assembly drawings released
 | part supplier defined
 | contract manufacturer (CM) defined | at the end of quarter.
 | Assembly plan aligned
 | sign-off assembly procedures and layout
 | assembly work instructions aligned with CM
 | QC plan aligned
 | buy-off end-of-line test equipment
 | trial run
 | 1st full product released | all FMEA risks closed, all SHOULD requirements met
Phase 4: Manufacturing | Production
 | Yield improvement plan aligned
 | Design improvement plan aligned
 | End-of-life/ End-of-Production plan aligned
Future | Implement yield improvement plan | TBD
 | Implement design improvement plan | TBD
 | Implement EoL/EoP plan | TBD

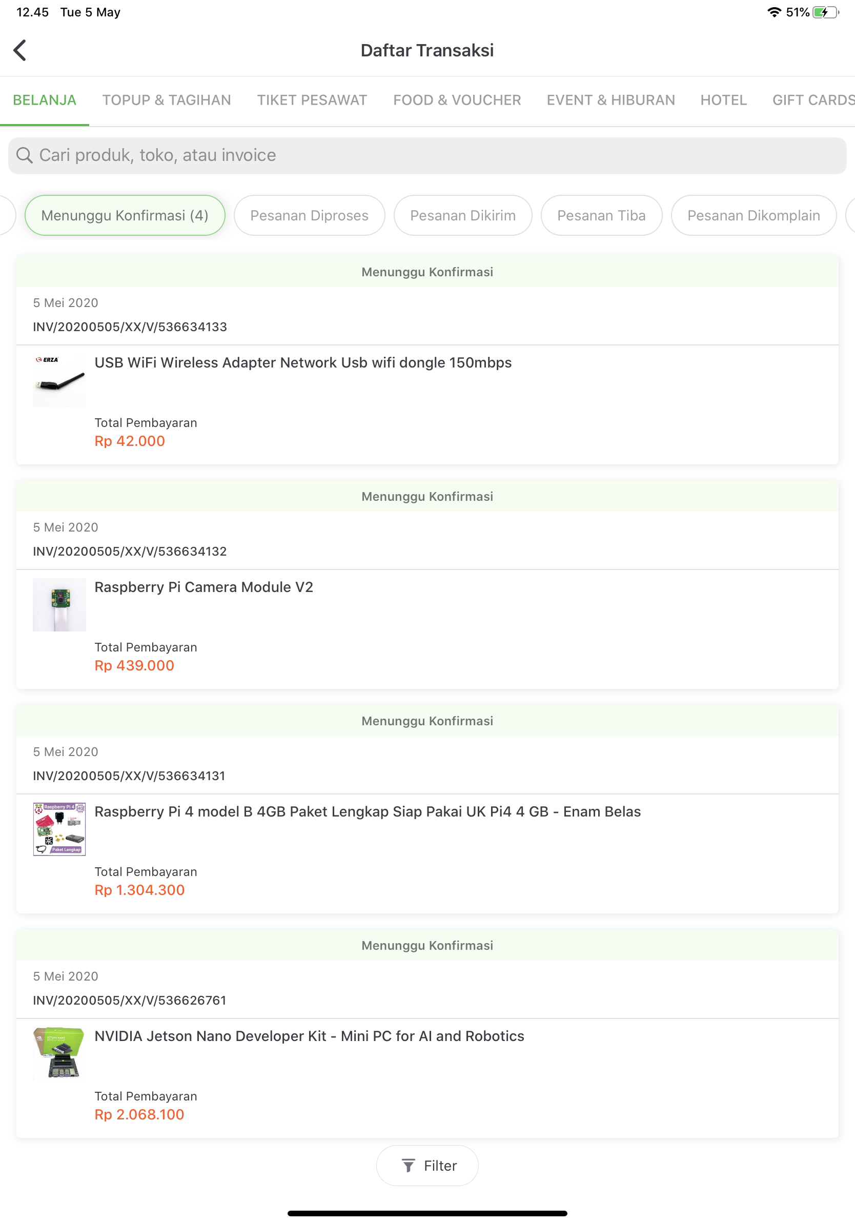
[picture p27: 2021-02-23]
operations_management/Invoices/July 2020/IMG_0218.PNG

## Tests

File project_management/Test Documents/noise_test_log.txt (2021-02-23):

Device Temperature Measurement by Adibaby
[17/08/2020]

Procedure:
1. turn on the device.
2. measure noise with app for every minute 1m away from the device.
3. terminate test when noise is higher than 62dB. device fails the test.
4. if average noise per minute is lower than 62dB for 5 minutes, device passes the test.

Test Log:
[14:21] test started. initial noise 57dB.
[14:22] noise 55dB.
[14:23] noise 55dB.
[14:24] noise 56dB.
[14:25] noise 56dB.
[14:26] noise 56dB. test stopped, device passed.

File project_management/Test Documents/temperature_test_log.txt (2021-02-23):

{"timestamp": "2020-08-21 23:27:16", "temperature": "49.0", "ai_alive": 1, "video_player_alive": 1, "cpu_usage": "41.8", "memory_usage": "297 / 1753"}
{"timestamp": "2020-08-21 23:57:19", "temperature": "58.0", "ai_alive": 1, "video_player_alive": 1, "cpu_usage": "62.4", "memory_usage": "303 / 1753"}
{"timestamp": "2020-08-22 00:27:23", "temperature": "59.0", "ai_alive": 1, "video_player_alive": 1, "cpu_usage": "61.9", "memory_usage": "306 / 1753"}
{"timestamp": "2020-08-22 00:57:27", "temperature": "56.0", "ai_alive": 1, "video_player_alive": 1, "cpu_usage": "60.8", "memory_usage": "327 / 1753"}
{"timestamp": "2020-08-22 01:27:31", "temperature": "55.0", "ai_alive": 1, "video_player_alive": 1, "cpu_usage": "50.7", "memory_usage": "313 / 1753"}
{"timestamp": "2020-08-22 01:57:35", "temperature": "55.0", "ai_alive": 1, "video_player_alive": 1, "cpu_usage": "50.8", "memory_usage": "308 / 1753"}
{"timestamp": "2020-08-22 02:27:40", "temperature": "57.0", "ai_alive": 1, "video_player_alive": 1, "cpu_usage": "51.9", "memory_usage": "316 / 1753"}
{"timestamp": "2020-08-22 02:57:45", "temperature": "55.0", "ai_alive": 1, "video_player_alive": 1, "cpu_usage": "52.2", "memory_usage": "314 / 1753"}
{"timestamp": "2020-08-22 03:27:49", "temperature": "55.0", "ai_alive": 1, "video_player_alive": 1, "cpu_usage": "50.8", "memory_usage": "316 / 1753"}
{"timestamp": "2020-08-22 03:57:52", "temperature": "56.0", "ai_alive": 1, "video_player_alive": 1, "cpu_usage": "50.8", "memory_usage": "318 / 1753"}
{"timestamp": "2020-08-22 04:27:56", "temperature": "55.0", "ai_alive": 1, "video_player_alive": 1, "cpu_usage": "50.9", "memory_usage": "320 / 1753"}
{"timestamp": "2020-08-22 04:58:00", "temperature": "55.0", "ai_alive": 1, "video_player_alive": 1, "cpu_usage": "50.8", "memory_usage": "321 / 1753"}
{"timestamp": "2020-08-22 05:28:05", "temperature": "56.0", "ai_alive": 1, "video_player_alive": 1, "cpu_usage": "50.9", "memory_usage": "326 / 1753"}
{"timestamp": "2020-08-22 05:58:10", "temperature": "56.0", "ai_alive": 1, "video_player_alive": 1, "cpu_usage": "51.1", "memory_usage": "326 / 1753"}
{"timestamp": "2020-08-22 06:28:13", "temperature": "57.0", "ai_alive": 1, "video_player_alive": 1, "cpu_usage": "50.9", "memory_usage": "329 / 1753"}
{"timestamp": "2020-08-22 06:58:17", "temperature": "59.0", "ai_alive": 1, "video_player_alive": 1, "cpu_usage": "56.2", "memory_usage": "338 / 1753"}
{"timestamp": "2020-08-22 07:28:21", "temperature": "55.0", "ai_alive": 1, "video_player_alive": 1, "cpu_usage": "46.4", "memory_usage": "337 / 1753"}
{"timestamp": "2020-08-22 07:58:26", "temperature": "60.0", "ai_alive": 1, "video_player_alive": 1, "cpu_usage": "54.5", "memory_usage": "342 / 1753"}
{"timestamp": "2020-08-22 08:28:31", "temperature": "59.0", "ai_alive": 1, "video_player_alive": 1, "cpu_usage": "62.9", "memory_usage": "345 / 1753"}
{"timestamp": "2020-08-22 08:58:35", "temperature": "56.0", "ai_alive": 1, "video_player_alive": 1, "cpu_usage": "56.7", "memory_usage": "342 / 1753"}
{"timestamp": "2020-08-22 09:28:39", "temperature": "55.0", "ai_alive": 1, "video_player_alive": 1, "cpu_usage": "50.9", "memory_usage": "344 / 1753"}
{"timestamp": "2020-08-22 09:58:43", "temperature": "55.0", "ai_alive": 1, "video_player_alive": 1, "cpu_usage": "50.6", "memory_usage": "344 / 1753"}
{"timestamp": "2020-08-22 10:28:46", "temperature": "55.0", "ai_alive": 1, "video_player_alive": 1, "cpu_usage": "50.7", "memory_usage": "349 / 1753"}
{"timestamp": "2020-08-22 10:58:51", "temperature": "55.0", "ai_alive": 1, "video_player_alive": 1, "cpu_usage": "50.6", "memory_usage": "354 / 1753"}
{"timestamp": "2020-08-22 11:28:55", "temperature": "54.0", "ai_alive": 1, "video_player_alive": 1, "cpu_usage": "50.5", "memory_usage": "350 / 1753"}
{"timestamp": "2020-08-22 11:59:00", "temperature": "55.0", "ai_alive": 1, "video_player_alive": 1, "cpu_usage": "50.9", "memory_usage": "350 / 1753"}
{"timestamp": "2020-08-22 12:29:04", "temperature": "55.0", "ai_alive": 1, "video_player_alive": 1, "cpu_usage": "51.1", "memory_usage": "356 / 1753"}
{"timestamp": "2020-08-22 12:59:07", "temperature": "53.0", "ai_alive": 1, "video_player_alive": 1, "cpu_usage": "50.6", "memory_usage": "362 / 1753"}
{"timestamp": "2020-08-22 13:29:11", "temperature": "54.0", "ai_alive": 1, "video_player_alive": 1, "cpu_usage": "50.5", "memory_usage": "362 / 1753"}
{"timestamp": "2020-08-22 13:59:16", "temperature": "53.0", "ai_alive": 1, "video_player_alive": 1, "cpu_usage": "50.7", "memory_usage": "365 / 1753"}
{"timestamp": "2020-08-22 14:29:20", "temperature": "55.0", "ai_alive": 1, "video_player_alive": 1, "cpu_usage": "50.7", "memory_usage": "363 / 1753"}
{"timestamp": "2020-08-22 14:59:25", "temperature": "54.0", "ai_alive": 1, "video_player_alive": 1, "cpu_usage": "50.8", "memory_usage": "363 / 1753"}
{"timestamp": "2020-08-22 15:29:29", "temperature": "54.0", "ai_alive": 1, "video_player_alive": 1, "cpu_usage": "50.7", "memory_usage": "366 / 1753"}
{"timestamp": "2020-08-22 15:59:32", "temperature": "51.0", "ai_alive": 1, "video_player_alive": 1, "cpu_usage": "50.5", "memory_usage": "369 / 1753"}
{"timestamp": "2020-08-22 16:29:36", "temperature": "54.0", "ai_alive": 1, "video_player_alive": 1, "cpu_usage": "50.6", "memory_usage": "370 / 1753"}
{"timestamp": "2020-08-22 16:59:40", "temperature": "54.0", "ai_alive": 1, "video_player_alive": 1, "cpu_usage": "50.7", "memory_usage": "374 / 1753"}
{"timestamp": "2020-08-22 17:29:45", "temperature": "54.0", "ai_alive": 1, "video_player_alive": 1, "cpu_usage": "50.8", "memory_usage": "374 / 1753"}
{"timestamp": "2020-08-22 17:59:49", "temperature": "53.0", "ai_alive": 1, "video_player_alive": 1, "cpu_usage": "50.8", "memory_usage": "378 / 1753"}
{"timestamp": "2020-08-22 18:29:52", "temperature": "54.0", "ai_alive": 1, "video_player_alive": 1, "cpu_usage": "50.7", "memory_usage": "380 / 1753"}
{"timestamp": "2020-08-22 18:59:56", "temperature": "54.0", "ai_alive": 1, "video_player_alive": 1, "cpu_usage": "50.6", "memory_usage": "380 / 1753"}
{"timestamp": "2020-08-22 19:30:01", "temperature": "54.0", "ai_alive": 1, "video_player_alive": 1, "cpu_usage": "50.8", "memory_usage": "380 / 1753"}
{"timestamp": "2020-08-22 20:00:05", "temperature": "54.0", "ai_alive": 1, "video_player_alive": 1, "cpu_usage": "50.7", "memory_usage": "380 / 1753"}
{"timestamp": "2020-08-22 20:30:10", "temperature": "53.0", "ai_alive": 1, "video_player_alive": 1, "cpu_usage": "50.8", "memory_usage": "393 / 1753"}
{"timestamp": "2020-08-22 21:00:14", "temperature": "54.0", "ai_alive": 1, "video_player_alive": 1, "cpu_usage": "51.0", "memory_usage": "387 / 1753"}
{"timestamp": "2020-08-22 21:30:17", "temperature": "55.0", "ai_alive": 1, "video_player_alive": 1, "cpu_usage": "50.7", "memory_usage": "389 / 1753"}
{"timestamp": "2020-08-22 22:00:21", "temperature": "54.0", "ai_alive": 1, "video_player_alive": 1, "cpu_usage": "50.7", "memory_usage": "391 / 1753"}
{"timestamp": "2020-08-22 22:30:26", "temperature": "54.0", "ai_alive": 1, "video_player_alive": 1, "cpu_usage": "50.7", "memory_usage": "394 / 1753"}
{"timestamp": "2020-08-22 23:00:30", "temperature": "54.0", "ai_alive": 1, "video_player_alive": 1, "cpu_usage": "50.8", "memory_usage": "403 / 1753"}
{"timestamp": "2020-08-22 23:30:35", "temperature": "56.0", "ai_alive": 1, "video_player_alive": 1, "cpu_usage": "50.9", "memory_usage": "400 / 1753"}
{"timestamp": "2020-08-23 00:00:39", "temperature": "55.0", "ai_alive": 1, "video_player_alive": 1, "cpu_usage": "50.8", "memory_usage": "398 / 1753"}

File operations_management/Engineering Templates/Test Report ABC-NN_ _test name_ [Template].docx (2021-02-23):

### Test Report ABC-NN: <insert name of the test here>

This test report must be read in conjunction with Test Plan ABC-NN: <insert name of the test here>

#### Signoff code: abc123xyz

#### Clause 1

##### Objective:

<state objective here>

##### Equipment and Materials:

1. <equipment 1>
2. <material 1>
3. <material 2>

##### Test Setup:

<insert image of the setup with labels> e.g.

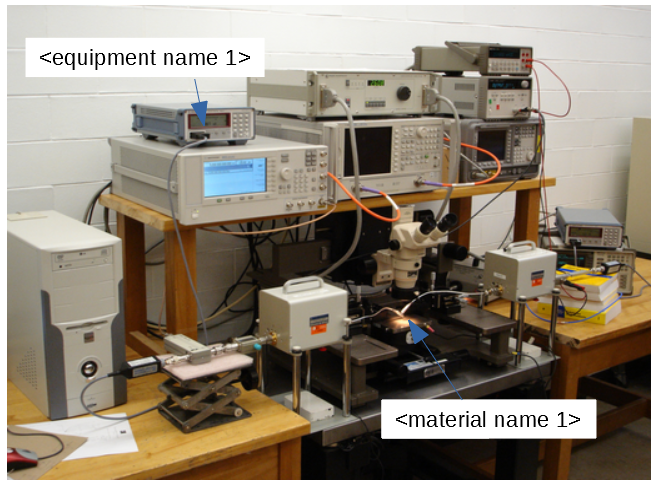
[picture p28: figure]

<insert description of each label>

###### Setup instructions

<insert placement instruction> e.g. connect the wire of <equipment xx> to the <equipment yy>

###### Perform these checks before performing the test

<insert checks here>

##### Procedure

1. <load sample>
2. <perform test>
3. <measure data>

##### Results

Input | Output
<input param 1> | <output 1>
<input param 2> | <output 2>

###### Conclusion

<summarize result into 1 sentence>

<pass/fail the related requirement?>

<further tests to be done?>

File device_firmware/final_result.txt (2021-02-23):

{"device_id": 69, "timestamp": "2020-08-29 07:48:19", "advertiser": "test_video-00", "image": "/9j/4AAQSkZJRgABAQAAAQABAAD/2wBDAAgGBgcGBQgHBwcJCQgKDBQNDAsLDBkSEw8UHRofHh0aHBwgJC4nICIsIxwcKDcpLDAxNDQ0Hyc5PTgyPC4zNDL/2wBDAQkJCQwLDBgNDRgyIRwhMjIyMjIyMjIyMjIyMjIyMjIyMjIyMjIyMjIyMjIyMjIyMjIyMjIyMjIyMjIyMjIyMjL/wAARCALQBQADASIAAhEBAxEB/8QAHwAAAQUBAQEBAQEAAAAAAAAAAAECAwQFBgcICQoL/8QAtRAAAgEDAwIEAwUFBAQAAAF9AQIDAAQRBRIhMUEGE1FhByJxFDKBkaEII0KxwRVS0fAkM2JyggkKFhcYGRolJicoKSo0NTY3ODk6Q0RFRkdISUpTVFVWV1hZWmNkZWZnaGlqc3R1dnd4eXqDhIWGh4iJipKTlJWWl5iZmqKjpKWmp6ipqrKztLW2t7i5usLDxMXGx8jJytLT1NXW19jZ2uHi4+Tl5ufo6erx8vP09fb3+Pn6/8QAHwEAAwEBAQEBAQEBAQAAAAAAAAECAwQFBgcICQoL/8QAtREAAgECBAQDBAcFBAQAAQJ3AAECAxEEBSExBhJBUQdhcRMiMoEIFEKRobHBCSMzUvAVYnLRChYkNOEl8RcYGRomJygpKjU2Nzg5OkNERUZHSElKU1RVVldYWVpjZGVmZ2hpanN0dXZ3eHl6goOEhYaHiImKkpOUlZaXmJmaoqOkpaanqKmqsrO0tba3uLm6wsPExcbHyMnK0tPU1dbX2Nna4uPk5ebn6Onq8vP09fb3+Pn6/9oADAMBAAIRAxEAPwD3+iiigAooooAKKKKACiiigAooooAKKKKACiiigAooooAKKKKACiiigAooooAKKKKACiiigAooooAKKKKACiiigAooooAKKKKACiiigAooooAKKKKACiiigAooooAKKKKACiiigAooooAKKKKACiiigAooooAKKKKACiiigAooooAKKKKACiiigAooooAKKKKACiiigAooooAKKKKACiiigAooooAKKKKACiiigAooooAKKKKACiiigAooooAKKKKACiiigAooopAFNLgCmM/NMZqlsBXlpnm8VC7DNIXApAOklbBFZUz5kOTVq4kwhxWack5ZuKaGP80D1xTfN9vzpvyDqaaXTFMBwlYngCmkuelAlQdvyppuOeKAAhyeaXa2KiaY7qYZXPc0ATFM5oCr61BliMk800n3pgWNyDPOKaXUdOagOPWkLLSAlaX0FJ559KgaRKaZgvanYCcyN0700s5PWoPO4o81zzRYRYDEnrxSFiPpVcyEZJJpA5aiwFrcD1qaBPMIqtAhdsDpWpGgRQKAJFwqil3VHnmjBNBI7dzSE8U3nH86Q5oACeeKYeeho5ppH50AIeaQ9fegjPJpDQIQnpk0xjinE0wgnigYLywGM1o2tuAoYjiora3x8zUl/frbx7FYZx2piJr7UY7ZCqkZrnS02oT4XOM9aiRZtQn4zgmuq0/T4rOEMwGRV6RQrC6ZpkdpGJJAM+9V9X1lYUMacn2qvrGtiMGKI/N0rlZZmlYsxJNTvqxpD5pmmcuzZzUWcUmeabmqGOJAHBzTS3NMLfnULyDGKAHu4B61XllHIz2pjy545FRhS5FMABZzU6Q45I609Igoz1qQdOM4oEKBhsCnAHOeaQDNPxkjmkAKM1IqUqp9c1Mqc9eaQCIn51MkZ/8ArU5I+KtxxeueKQhkcOTz+FWVjWMc9Ka0qQrnOMVnXN+SSF6UgSLk94qKQDx61lXF0zk84FVpJyc8mq7Sc4zkU7FJEkkn41XZyeN1ISSeacF3UxnuVFFFSMKKKKACiiigAooooAKKKKACiiigAooooAKKKKACiiigAooooAKKKKACiiigAooooAKKKKACiiigAooooAKKKKACiiigAooooAKKKKACiiigAooooAKKKKACiiigAooooAKKKKACiiigAooooAKKKKACiiigAooooAKKKKACiiigAooooAKKKKACiiigAooooAKKKKACiiigAooooAKKKKACiiigAooooAKKKKACiiigAooooAKKKKACiiigAooooAKY74FOJwKqTPUsAaT3qNnyOtQs9RO+R1pDJN/NNaTA7VWWQ7z6CiSXAJ7CgCC7nOSo5qmdxHWknn3SHFReYxzziqsBNjnk8035QeuT6VFknvSY96AJN6Ck81eRTCvWk288A0AK0uTTfMf2pdp9KPKcjpQA0u5GM/jTctzyalEDHr/Kj7Mx70xXIM570mRwasm0YCnfZKAuUtw6mg89q0BaAgcUv2bHbNArmaN5HA6UoVvStIwgelNKKDQFzP8AKdulTxWjswGetWY49zACtW3t1jGTQK5Bb2YiGe9T+UOasHbjtTNwpCuQmIDoPzpu0DtUrNmmFqAGEYNRsOcU8tTCfU0AMIxxTSPT9KcT9KjLj8qAA9KY2BxSGTJpvmZOO9MB45qeGD+JuBRDGMbjVbUNRW3jKqfm7UBclv8AUI7aPapGccVgRrNqNx6gnNMiim1CfvgmupsrSKwg3ORmr0ihD7GxhsYQzgAgd6y9X1zGYojzUGr62WzFE341zjSF23E8mpSvqx2HySmRyzEknuaZmmk8UhaqGOzx6U1m49c01n5GarvLjIoAkeTAqs8pY8daaWLVJDFnk0wESPcRxVlU2gUoXB9qcKLgLjPQe1KBmgD0qVF45FIQirUqpzmlVcdBn61Yjj5zjj6UgGpH6dasxwk/hUkcHc1K0kcXUgY/SlcaHJGsQBbFQ3F4qDC49OKpXN+SSAeKzpZiSST170kgsWJ7tmzknH1qm0uQaiaTPTkUzlvemMVmPNIo3flUipkDjNWIrZmNMZXWJuxq5DaM+PTrWha6cWIyvFa9tYhR0H5VDkFjorbWg2Axz6+1aMV9DKOuK5GXTLmDnGcelRR3U8DANu4rfkTJv2O8BDDIOaWuUttcIxuY5rXg1eN8biMetQ4NBc1KKijuI5BwwqWoKCiiigAooooAKKKKACiiigAooooAKKKKACiiigAooooAKKKKACiiigAooooAKKKKACiiigAooooAKKKKACiiigAooooAKKKKACiiigAooooAKKKKACiiigAooooAKKKKACiiigAooooAKKKKACiiigAooooAKKKKACiiigAooooAKKKKACiiigAooooAKKKKACiiigAooooAKKKKACiiigAooooAKKKKACiiigAooooAKKKKACiiikBDK2BVGRua0HUEVUdBmpApkn0qKTOyrpQVHIo44oC5RiQ4JpJVIXJxV1UAWq1wyqCMimFzLMO5icc08W5NOacL0HFOimLNyKqwrjRbZ7U4WvtV+MKwxUhVRzigLmeLX2pwtBkYqw1xGpxTDdKBQK4wWqjtSm3UU1rviomuTjrQBP5ad6Tai+lVWnZqY0hNFhFvdGDx0Hem+YgNVCWPFByelMCz9oXHGDUZmz0FQlTnqaCpH1oAe8xx1qHJY5/rSiF5D8v45q5BYFTljQA60i28tV7cAKYqKoAFBx60gFLg/wD66YzgHigkDvTCeKQgL0xpDQTTCc+1AxCxx1qMse9OOcVG360wI3b3xURb07e1Oc81DvX+8ooAfnJ781Zhj7uB+dMhRfvbhx3qnqGpLCCiHn2oAmv9TWAbUxmsiGGXULjJyRmore3lv58sCR+ddNDFDp0G5sBsVfwiJreCHToNzYzisHV9aaVmjjOB2NVtV1l52MaN8vesVnznJ5oS6sZI0hYkk5+tJu59Ki3Dmk8ymMmLDHWojIOmfwpjuMdTgVCZSTjsaAHySZPFRDc55pURnOanRADTAWKIZ5FSgYHANNHAp+D2qQFHX9M4p6jgc8UijNTIuT0oECJ+VTpGfT60LHmrUUXfFIBI4v8A9dWkRU5bjHemPMkSn+lZ9xfFs7T1qQLs94qDCHn0rKmu2fnPFQST5PJPPvUDPmmkUkSPKDwP/wBdQlyf60YLU+OItxg+1MBgWp4oS+OM5q1BZsx+7+dbFrp2MEjj1pOSQ7Gfb2G/Hy9a2LfTguMjmrsNqE7YNWguBxWTlcpEMcCqvA/SpwMDvQO39KXp2qQOoaNHGGUGqVxpVvOD8oBNX6K3TaIscvdeHipzFxWXLZ3VsxPzYFd5UckEcgwyitFUfUXKcTDqM0BwxPHqa17TW8/eNXrrRIZslQAfpWNdaDLF80eeKq8ZCsdDBqUUgGSAatrIrjINcGVu7U4IPFWoNXlTG4mpdPsPU7SisK211WwGIP1rThvoZehxUOLQ7lqikDBhkEGlqRhRRRQAUUUUAFFFFABRRRQAUUUUAFFFFABRRRQAUUUUAFFFFABRRRQAUUUUAFFFFABRRRQAUUUUAFFFFABRRRQAUUUUAFFFFABRRRQAUUUUAFFFFABRRRQAUUUUAFFFFABRRRQAUUUUAFFFFABRRRQAUUUUAFFFFABRRRQAUUUUAFFFFABRRRQAUUUUAFFFFABRRRQAUUUUAFFFFABRRRQAUUUUAFFFFABRRRQBFK4UVTkk5xmrM6Fh8vWqDwyluhqRCmWoJJDUhtpSaQ2TmmBAZeKrS4ck5q99hIpPsPcmgDLMQFKq7RWn9jQcGj7Kg7U7gUopGDgdqnmkPl1N5KjtUc8RZCBzSAxzueRsk9alEZ71OlswJ4p/kNjofyqhFbZSlRmrH2Zz24pGtHPUgfjQBX2pS4UCp1sz3fn2FKbYY6k0BYrZApN/tVk2h7KxoFjIf+WZx70AVdxJwFqVIXfGRV5LFlH3FBqX7OwH3lFK4EMUWzoKcQc1J5ary0tMYQgcyk0hDMj1qN5FXqRTzJZqCSwP1NV3vrFCSSpIoDQTzl6VIHDdFY/hVZ9Zs0PAWoH8Qwr90D6inZhdGhh26IfxpPJnY/dArIfxOAcCqsniR2ORj8aOVgdB9llbq6j8aY9njrMB9K5hvEE3UHioH1u4f+I/hT5GFzopYIVPMpNUpvKT7hz7k1htqFw2CQx/Co3vpO4P1p8jA1ZdRMMeAapW8Ul7PuIJyarRlrmQAg8+1bSSR2MWTgEVVrBc0ojDp8AzjOK5/UtWe5dlVvlqlf6o9w21W4HWs4yUJdxonaTJzTS/PBqAyY5PWmmUHnrVWAnL01pPwqsZcUAluv4UASFyTx609I+eaRE2j3NSr1GKQEiqFFOB9ab2p6jikA9eDUi9MU0Lz0FWETp60gEQHoKsxxZHanRw4OT2qVpFiHXmkIkRAgyainuxGML/ADqnNe5OORVJ5Sx6/WkUkWJrlnbrVRpDzzxTC+fwoCk0DsKSfrTliL1JDCzn5V4NaVrp7NtJX8jQ3YZShtWdhxnNattp2cZHP0rRtrAJjIFaUUSqves5T7DsUrexCAZFX0iVcYAH0p6gelLyc49azAXApD60c5obAGO9ACng49aR2G3moJrqOIZJH51h32tAbljbJppXA9NooorYkKKKKACgjPWiigCCazhnB3IPyrJutAjk+ZBznit2iqUmgOJuNGubdtyAnmqqXFzbPh1PvkV3xVW6gGqs+mwTg5Uc+1WqncVjnLXWmRgGYj61s22sxyDDkZqhdeHBy0XH0rJl0+7tiSAxx6U7RkLY7aO5ilGVYVLXBR6hNbsN+4YrUtvEDA/Malw7DudTRWbb6xDKBuODV9JUkHysDUNNDH0UUUgCiiigAooooAKKKKACiiigAooooAKKKKACiiigAooooAKKKKACiiigAooooAKKKKACiiigAooooAKKKKACiiigAooooAKKKKACiiigAooooAKKKKACiiigAooooAKKKKACiiigAooooAKKKKACiiigAooooAKKKKACiiigAooooAKKKKACiiigAooooAKKKKACiiigAooooAKKM0mRQAtFNLexpvmMf4fzNAD6aR7VGWc+gppLY5cUhEp+lRMe/FRnb3k/Kms0fdj+dFhDmI9aYWXuajae2Xqw/Oon1G1j6uo/GiwXJiyn1pv/AAE1Tk160TP7wfhVV/E9qvQk0+ViujX2t/c/Ojy3IPAFc9J4si5KqT+NVJPFrdo+3rT5GFzqzEe7AU0wp3f9K4yTxTcsPlwKrt4gvHJ+dqfIwud1shUctSGW1UckfnXAvqF/ITgyfhTM6g/QSZ+tP2Yanetf2UY5ZBUD63Zx/wAa1xX2O+kzkgZ96UaVcP8AemUD6U+RBqdVJ4ltl9D9KqSeK0H3QT/WsQaN/enY/SpBo9suNzMx+uKOWIi5J4qc5wMH3NVJfEk7AkNj8eKd9gsU+8o/E0AWEXSOPj2p2iBTbXLtzwzc+lMa9vpTwJD9BWiLy0QfLt+gFMOqRDO1TxRp2CyM4pqEox5b49zilGnX79QB9Wq0+r4HC1Wk1iTsAKd2Fh39j3HVpUWpBo4z89x+VUG1aduNwA9qj/tCY/8ALQ0tR2NddJtRyzs3PrS/ZNPj5K5/GsU3Lngsx/GozK/cn8TRZjN3fYRdI0696jk1C2ReFUY9BWGWJ9frUbFu1Fgsac+poR8oI+lZ8l0H5qnKT0qHeQO9OwjatboQfN3qpeag0zEKflqgXYjqcU0niiwEpkzTC/pTOv0pO9MY4t1/pSBvemH0pRTESKMnn61Ogxiq6tg4qwuQPapYyZSaePXvUaAk1Kfbr6VID1GasIgIHXFMhXcAatxx+v1pMAjiJ7VaRFTk1G0ixiqst0SeOlIC1NdBRhT3qjLcFiTzUDyE8EVFyaCkiV3J7mmDJpyqSeP0qzDas5HGRQMrpEWPGKv29kznOPxq/aaf0LCteC0VAOPyqHKw0ijbaeAoJH51qw26p2FTIgXtThWTbYxQoGMCn5zjNNHNP7UgGinZ79ajeVI1yxHHrWZd6xHECFOaANSSdI0JJANYl7rCxghSMisW81aWYkAms1pC/Uk1oodxF261KSYn5jVBmJbk5puTz60VokkI93ooopCCiiigAooooAKKKKACk5paKAELDvTHhjkGCoqSmlB24oEZ1zo0E4OABWHd+HXTLR5z2rqzvX3FHmKeGGPrVqTQHBPBeWnYkD0qa31eaEgNketdpJawzjlRz3FZd3oMMo+Vefaq5k9wILXxApADmteDUYJsYYAmuUutCmhJMZNUN93acMrYHSjlT2A9EBB6HNLXEWuvSxYDE4rctNfilwHI9zUODQzboqCK6hlHysPpmp6kAooooAKKKKACiiigAooooAKKKKACiiigAooooAKKKKACiiigAooooAKKKKACiiigAooooAKKKKACiiigAooooAKKKKACiiigAooooAKKKKACiiigAooooAKKKKACiiigAooooAKKKKACiiigAooooAKKKKACikyPWgso7igBaKYZFHemtcRr1bH40Bcloqq1/AvWRR+NQPrNpH1lWnZiujRorFfxHZp/y0zVaTxVbDpuNPlYcx0dFci/i5Oixkj3NVpPFspJ2ooGKfIxcx224DuKTevrXAP4pu2PDAfSq767fycCR6PZsLnohnQd6ja7hUcuv51502oahLx+9NRs9/Jwdw+rU+QLs9CfVrVOsqD8aqyeIrJP+WwrhPsV045dR+tKNLlb70v6UcqDU69/FNmAcMx+gqrJ4uiydqMR9a50aSP4pHb6VIulwjBYMfqaLRFqacvi9uixj8TVWTxVcMMLtFRfYrVOCEHuTShbRB/yzA9hT07BYik8Q3sgwGP4CoDqOoy9PNI+lXDcWq9G+mBUZv4BwFY/pT+QWRULX8nZ/wATij7Lev1IH1NWDqajpEPxNMbU26Kqj8KLsLEQ0yduGlUfQU8aT/emb8KjbU5T0YD6CoXv5T/y0bP1ouwLo0mEfeZz9TUgsLNOoXPu1ZTXTk4LE0wzn1NGoGxtso+gj/Kl+12idMfgKw/MJoLseKLDNo6hDnhTx+FNOqIBgR/nWNlvTJpMORRYVjWbVWx8qqKibVJT/Fj6Cs8RsRS+UxIHP4UWCxabUJiT85wfSoWu3/vH86aLckUv2f2NA7DDcMe+aaZmPA4qwLb0FO+ykjpQBTLueKQljnANXltD0Ipy2vbbQBnbX6c1BLlRitk23XIqhd25Uk46e1AFDn3qWL5mApNvGKs2tuWY8cZoAXyc9qXyuvBq/wCT7Zo8rrxSuBQMOP8A69RPGMetaDJx7VBIoxgUAZUyc/1qq4wcdDWlOvp1qhIrFvunn2qkBF35pOKf5TY+6cfSjyX9KAGcdv0pDUwt3Pal+zH1/CgCvQCKn+z+5o8peaLhYhHWrSZ9f0qMRjOKsxrgd6TAei8cdqsrFk0QoO9TGQIvFSwJY1CDJNI9wAMA1Vknz06fWoS+fUVI7ErzFiefpUbPnpTMknpT0Qnj+lBQ0LU0cDMRxVm3si/XNa9vYYAyOcdKlySCxSt7Es2cZH0rYtrEIBkVYhgVOMCrCjp6Vm5XKsCRqFAAAqQdOKMUgNQMmA9Dil6DiomkVQSTwKo3GqRxr1H50CNAyBQMnGapXWqRQKRu5Fc7d6y8hKqT0rKluJJDlmNWoPqK5rXusvKxCHArIeVnJ3Nmo8mkJOD6VokkK47JIpCTn1pM5pMgAVQx3vikJxRngimnpQB71RRRUkhRRRQAUUUUAFFFFABRRRQAUUUUAFIVB7UtFAERiP8ACcfSmb5Y+o3CrFFO4iv50T8ONv1qKbT7edc4HNWXhR/aq72zocxsR9KaYGNd+HY3yyDB9qxptIurf7hJFdj580f303Cl863m4YbT/tCqUmhHER3l1bHEm4fWta18QsuNxyPrW1PpcE65ABHtWJd+HeS0eQc07pjNy21iGYANgE+lXkmjkHysDXAyWd5ZsSASO1Og1eeBhvLD60nDsM9Aorm7TxCDgORitiDUoJv4sVDTQFyikVlYZUg/SlpAFFFFABRRRQAUUUUAFFFFABRRRQAUUUUAFFFFABRRRQAUUUUAFFFFABRRRQAUUUUAFFFFABRRRQAUUUUAFFFFABRRSZHqKAFopMikLqOrAfjQA6iomuYF+9Kg/GoX1K0T70607MV0W6KzZNdsI+swP0qu/iayXOCTRysLo2qK5yTxZbqMrGxqs/i/P3IhT5GFzrKMj1rin8VTtnaAKrP4lvW+6xH0p+zYXO9yBSb1zjcK89OsahL3kP0BqW0nv5blRlxnqTT9mGp3M11FD991H41UfWLZM/vU/OuZ1a1uyFcPkdCCcVkiyuWGS4oUUGp2reIrJeso/Kq8nii1X7pJrlP7NfvJ+Qpw0wEfeY0+WIanQSeLIv4VJ/Gq7+LT/DGKyxpkQ6hvxNOFlbp1CD6mnaIrFmTxZcE/KFH4VXfxLeyfdY/gKTZaJxuj/CjzrVP48/QUadgsQtq2oyfxSflUTS6hKed/51ZN9br0DH8KY2oxj7sf5mnfyCyK/kXznlvzalFhO33pFqRtV9I1z71G2qS9to/Ci7CyHjTWPWU/gKcNLT+Iufxqo2ozE/6w/gaY15Iert+dGozRGmwAcr+bUv2a1TP+r/PNZBuGJ5J5pplJPegNTazaIeHT8BSG6tgeC3HoKxd7fjSEtz7+9FgNg30A/gJHvUZ1NB92IfiaycOe1LtalYDSbU3B4VAPpmom1OY9Gxn0FUvKb3/KlEByeKdhWLDahKesjfgaha6c9WP4mk+zkml+zHv0oCxGZ2z3pDKx9c1YFrntTha0AUzIx6Unz+lXxan0py2vtQMzsMaPLY85rUFr7D8ad9l9vrQBlCFie9KIGxWuLUelOFrjtxRcRk/Zie2felFqfT9K2Ba8nj9KeLYdcUrgY62vbFOW1PXH5itgWoH8NPFuO4zQBkC1x26U8WmccVrC35J20/7KxOQhouK5kC0GBkVILTsB+la62b56U4Wp9RSuBkC04zinC1GP61r/AGZR1koMUIBy+aLgZQtsE8U4WwGDitPFup55+pphuLZegX8TSuBR+zAdqUQDjj9KtNfwAcBc1E2qIOnH4UXAi+yk9EJH0pr6cZVwU59aV9UOOMmom1KQ5wP1o1HqQnRMnJCj8asR6csQHzLVd76YngVE087dTRqIuPbxqOZPyqJ44FyNxP0qoTKR1NRlXOeTg0DLEi24zxmqztF/CBSGM45ppi74oAjkdCDgD8qrsoJ4AzVoxgGmmM9QKBlIoT2pPLxz2q55Z5yKaVAHrQBV8vjpTWTFWSR61EzKD1FAFdk/KmbDz1qcutMLjOOaLgRqmD/jVhAFxzUBbHQUbyR7UAWDLgYXAqMuT3qLfxxSgk0hjtx+tKqk9vxpY4yxwOa0LezJIJHFJjIIbZn6ggY71p21h0b171agttoHarqLjtWbn2KSEggRACAKthAvSmKMVIOKzYyRRilpoYA9aimuo4VyWFICwXA5JxVW41CKFck81j32s/IQh/KsOa6kmYlicVag2Js1rzWmk4Q8e1Y73Ekn3jUWc4puema0UUhD8im5zSZwMGjPfPFMQ7NJnvTaM5NMB3BPWjOPbNNJpSeM96ADPFNJyaD7U0nHHFAj36iiipAKKKKACiiigAooooAKKKKACiiigAooooAKKKKACiiigQhUN1ANV5LSN+gxVmkpgZzWs0RzE5pn2yWM4mj3D1FalMeJHHKincRQE1rcgg4BPUGqtzo1vOpwAauzabG+SvBqo1vd2xzG5I9D0pryGYd1oEkWTESKzyl7ZschiB6V1Y1F14niP1FP3Wl0OCuTVcz6gc5a6/NCwDkjHqcVvWviKNwA5FVrrQoZeVH4isW50W4t2/dMfoaPdYHcQ30E4yrirAIIyDXm63d5ZthgwA9K07PxI6EBialwYXO2orHtdegmADEZ9q047iKQfK4+lS00O5LRRSEgdSBSAWimmRB1YfnSGVP7woAfRTBKp6E/lShs9AaAHUUmfajP0oAWim71HUim+dH/AHhQBJRURuYh/GPzpjX1uo5lX86LCuWKKotqtovWVahbXbNTzIPwp2YXRqUViv4ls16HNQv4qtwOFp8rC50FFcw3itf4YxVd/FkhztVcUcjC519FcS3im7bpj8Krvr1++QC5/CnyMLnekgdTimNNEvV1H41wBvtTmPAl/lTSNSkPIcfVsU+TzDU7xr63TrKv51E2r2a9ZRXEfYr1jlmA+rUo0u4ON0qj6CjkXcNTr31+xQ/6yoH8T2ajjJ9K5oaQSBumJx6Cnro8Y+8zmjliFmbT+LIR92PNVpPFrdEjH41RGmWyD5h/301KtrYx84i/Fs07RCxJJ4quG6ACq7eI76QcMce1SedYRDh4h9BUTanaIThz9AtGnYLIjbVNSkHBlPpgU0y6nJzmT88VJ/bFvnhHP5Up1iPHEX5mnfyCyIDb30nVuvq9H9nXLfekUfrTzq7dokH51E2rTHpsH/AaLsNCQaS5HzT/AKU/+yE/ikcmqh1S4b/lpiomv5mzmRvzp6jNMaXbr1BP1anfYrRByI/xasZriQ9WJ/GmmVuTk0agbmLNO8X4UhubRf4h+C1hb3OTRlj0pWA2zf246bzTBq0cbZWMkj1NY4DHtRsY8/0osFjXuddkmwGRcD3qudUl7BR9BVAQse9KIGp2QWLTalOf48fhURvZTyZGz9aj+zt6cU4WpBPBo0Cw1rlzwWNR+aTVgWx6kU77GfQ80BYqbz+dJuerwteOlO+xkk4FAGd8+O9LtetNbT25+lOFpnHGKLgZXlP9M0vkNitf7IPTFOFpjtRcDHFsTThbH8K2Bae36U77LxwBRcDHFqepFO+zHOQD69K2BajuKX7MM0XAyBaEnkfnThacYxWuLcADjNPFueyk0riMgWmR0P5U77LjpWwLRs/cNO+xuew/Oi4XMcWvtSi16HFbAs/UqKcLRR1YUXFcyPsv+TThagVri3j7kn8KPKhA6Gi4GWLcDt9aX7OK0S1ug6KPqab9qgXulK4FIW4HrThbMeiGp21CEcbvyFMOpLjADH8KNQEFo+PuU4Wp/wBn86iOoluiH8TUTXsp6KBRqBcFsAeWAp/2eMdX/Lis03M7en4CkMly3RyPpQBpGOBf4jQTAg6fmayyk7jlnP40fZpWPI5osI0WuIB02/nTP7QhXPI/KqYsXPr9KlGntnoaAJW1NO2T+FRtqZwcKTT105vQ/lUi6Yc8rS0CyKralIRwv61Gby4bgYrSXS8dgKkGnIOrKPajQNDF864Y/eP5Uh+0P1ZvwNbf2WBerr78U1/skY5cGi6GYv2eU/eJJNOFm5rVN3aIM5H51C2q2ig/d+uaLgUhp79aeumseo5p512AHjAqGTxEnG39KVw1JxpZz0/OnjSzxwKzpPEbds/TFQP4hlPTP50XHZmz/ZgHUj86Q2MSnl1rnX1yduh4qu+qXLcbsUBys6Zre1XrJUDfZV/iNc017O3WT9aYZnI5dvzpD5Tfea2ToM+vNVmvIVPCqKxi7N1JzSbjnIphymm98nbFV2vc5wKpZOT2pCeKB2LLXRbvioTMx4zxUfJoxQFhS+eTTSc8c0pGBSYOOKAEPPApAAAcAe9OIP8A9bNJt6UBYQn8KYcnpUm3Pem7fagVhFGasxRbj0qNE56VeiXmk2NIuWlqCM4rTjjCgcDNVrQcevFXR9ORWUnqUhw4qVOnbBqMY9qilvI4gTkVIy9kAZ6VDNexwgnPNYd1rBJKqT7Y4rLmupJSdzGqUGxNmzc618xCN24Gayp7+WblmwKqEnFNz65q1FIVx7Nnk00GkJGO9HXkVQhT+lGabk+1AO3OaAFJ9aM9qbnvyKTPagB5Y+tJnvTc8U0n68e1AD88daO30pmfXrSZ68UxDycnAPPtSZ/Omk88U0tzQB9CUVSi1O3k/iA+tWlljf7rA1FhD6KMg0UDCiiigAooooAKKKKACiiigAooooAKKKKBBRRRQAlFFJmgAzRTSaM0xC5pDg9aaWpN3FMBkttFIMMorOuNLUtujO0+1aZNNJouBhMt7aH5WLr6GnLqi52zxkH1rXbB4IqnPaxSA8AZpgVmSzukwCvIrI1DRVHzxgD6Vdl0wr80TFfpVOWW9gUg5ZapeQMyTbXUByh3AVZttXmt2CyZHSrlvqER4nTafpTpre2uclMU79wRag15nTAlIpGv5GOTN+tYFzYPb/NGxGPSs43k6ttJ5o5UB2qaskQ+diTUo1+EAc9q4Mzyv1bFWIY/M5aUjPoKOVBZnaf8JFEM4qCTxSFJxWHHZWgHzuxPuamW205eu0/VqVogX28UydABVd/Etw3Q/lTM6bGMhY/yzThfaen3VT8Fp6dgsQtrt4/3SxB9BTDf6jICAJfyqz/a1svQE/QUw6zF2Qn8aL+Q9CAf2m5+4/pyaX7HqLjkgD3anNrRx8sY/OmHWZeyL+NF2Gg5dKu2+9Mo/WpBo0nV7g/gKqnWLk5+YAewqNtTum581vwo1A0F0ZOjSuaeNItVHzFifdqxzeTnkyMfxphmkfqxNGoG59isUz8sf4tmngafH/zyBrny7nuaPnPTOKVmM6H7ZYp0K/gtRnUrYDgMfoKwdrHNGx/rRYDaOrxAcRn86jbWOuIl/E1liJs8ZpfIb0NOyAvtrMnZUH4VE2rXB43gfQVXFufSnfZCSDj8KLILDjqVw3WVvwNRNdTHq7c9ealFmR/D+VPFmSTx9aNAsVDK56k00s59av8A2Ij+Hml+xEjp+lO47Ga27kmq7N7/AJ1sT2hWPgVltEd3TjvQA2M5PvVkRNgHJqOCItIAM1uQ2WUGVpNgZPkt+dOFuT2Nba2PGcCnCy5ORRcLGGLY9KctqfSt0WIHUU77IB2PWi4WMJbQ5HFO+yHuPrxW+LMHtT1sx6ClcDAFp0Hf6U5bI+lb32UemaVbX/ZOfai4GJ9jz/Dj6U4WXHArcFpj+E4p4tPYA/Wi4rmELM5p4s+ny1tfZgOpWl+zpnlx+VFwuY4s+Pu04WfqO1a3lxD+I0Yh75P40XC5lraAHpS/ZR9K0i0Cdl/E0xrm3XvGPxouK5SFsM+lOFtnsTU7ahCvRh+Aph1OMd2P0FIBPshP8BpRaNn7o/Gom1MH7qMaYdRk/hi/M09Q1LQtMYJKil+zDqXAqkb6dhwoH4U37TcnPzD8BQFmaHkxgfeJo8uIDODWaWumON7fnSeVM3VmP1NAWNPEKn7o/E003ECd4x+NZ4tHPrSiyY9RQFi419AvRh+AqNtRjHQk/QVENPY9qkGmsf4TRoKww6kD0QmozqDnog/E1bGlsP4cVINOA5O386NA0M03lw3QAZ9qaZ7ph94j6Ctb7DGOrCl+zwA8uM/Si4aGKRcseXb86PIlOc5OfetrbbKfvZPoKQy2qen40XC5kCzbGMGlWyJI4rSbUbSPqUH1NQvrtmg4dBRcCuunt6VKNNJ/hqJ/EkAztbJ7YFQP4mQn5Vc0rjsy+umMOoxUg04A8lR9TWG/iWQn5U/M1A/iC4PZR9c0XDlZ0wsYl6svFHkWy9X/ACrkX1u6YfeVfwqFtTuW/wCWzCi4+VnaH7Kme4+tNa5tEHYfU1w7XkzZzKx/GojK56kmkHIzuG1W0Tn5PzqFtet1GAyg+wri959SaQtQHIdVJ4jQHgk/SoJPEhOdqtx61znIpCG/CgfIjcfxDMc7R+ZqB9cuX4yBWVtJoK0D5UXH1S5fkymoHvJ3HMjGodp9KXZz9KAsgMzk/eJ/Gm729TTvLPTFHlnPINIZGSW7mkzU2yjy+eBQMiwfWjHGam2YPTNJ5f0PtQBDg570beam8s56UvlnjjBouBBj/OKTH4Cp/K5o8s0XEQ7aTb1OKn2EUeV6daAISvpSBasFPWkEXoKAK+zt370u30qfZkDH54pNvA4xRcCHb7Ck2k/WrGwDr1pMUXAg2mjHPSpsdqQqOtFxEWzik21KRRt46UXCw2NeatxAA4PT1qqPvVOsgUZJpMDXtWAUdfSpZrpIl68/WsQ6hsGFNU5rqSTq3FRy3Y7mnc6oxOFNZs07Sk5Y81XJoyOxH51aikK47eSeDRu70zPtSE4HH50wH54pAeKYDRnA46mgQ88j/Cmgn8PSm7vzoLen4UwHE9qCcVGTzRntQA8nnp+VJnNNORzSZFAh+fajdTCR3pCaYDi3b+dITxz0puee1J3oAdnnrSEkGkzgZozwf8KBHeR3LrjaxxxVyHVJ4yPmyPrWaTg9aUH8KY+U6GDxBKmAxrTg8QI/DY4rjMkYx+VOViO5pWQWPQItUt5MfMBVpZ43+64rzlLh48YY49jVmLUp4+j0uUVmegA5pa42DXpUOC/FaUPiFSBuqeUDoKKzodXgk6mrSXULgEOKLAT0U0MD0INLmkAtFJmjNABRmkzSZ5oAd2opuaTcadhDqTNJuHejPWgAJxTd1KTTTTARjTN1KxplAC5xTSwNBPbtTTTAG6VGx96UtTGNAyNulQyIGHKg/Wp+tKUBHI/A0AZE+nxSdgKzJ9NliJMTMMeldIyCoZI89qpMDlJbi6iUrIuRWVLMjsT0rs7m3R4zlRmuWvrJQ5OMVSYGc7so+U00XDj+I49qbJGytimMpC570xky3DlvvGrCMzdzVCEfMK1oY+BQxCDceKdsI61aSHNTpbe1K4yh5THpnApRF9fetNbUnjFTLZ5pXAyhCfelEB647VtLY+3NTLYZHT9KXMMwRbHnIqQWjcYH5it5dPBHSpksB6cUcwHOraH0p4smPauiFiM42j61ItkPSlzAc4tke4qQWP8As10QslA6Cni0GOlLmGc4NPOMYqVbA/3ea6EWYPb9KcLUf3aOYDAGn+1SCw74/Gt77OB1wPrR5SDqy0uYVzEWwHpzUosOela+2McbwfoKC0Q70XC5lDTx/do+wkH7vFaXnQj/APXTTdwKe34mi7C5Q+w47Uosv/1VbOoW46FD+NRtqsIBwy/gKNQuQmx3KR7elZk2gsz5VW/AVrNq6f7X4Com1Y54VqauFyrZ6GYiCVP41qi0AA4A+pqgdTk7R/rTDf3BHCACizDU1fs6j+JaPLiH8Q/Ksk3V0fb6Cm7rt+rsPpRYNTY2wgck00+SvGOfrWT5Ny2SXf8AOgWMrdSTRYVmaZuIF67fxNNN/ABw0f4VQGmufWpRpjHtT0CxMdTiH8X5LUbaouON5pV0o+n6VKuk57cfSjQLIqtqZP3Ub86jOoy9o/zJrRGlAcYH408adGOSVoug0Mg3lyecD8qaZ7pu+PwraFlApGXFKYrZerD8qLi0MP8A0lurvSfZ5m6sxH1rcJtVphurRemPzouBkCykPrThYN3zWg+qWafxRj6moH1+0Qf6xPw5ouMhGnH0/OpBpjf3aik8TW69GJ+gqu/ihM4Ac/hQGppDTCMfLThpy8Z2jHvWE3idzwsR/FqgfxHcMflRR9TQFmdOLGMdWUUv2e3XkuK5B9dvG6Mo/CoG1W7brMR9KA5WdsBar3pDNapnP61wjXty/wB6eQ/jUTTO3VmP1NA+VneNqFomcmMfU1C2t2iHh0rh9xOSaTJoDkOxfxHbjo+foKgk8TRdg5rlcnNJhs0D5EdE/iRifljb8SKgbxDcHogH4msQgkd6UKSaQcqNJ9bumPDKPwqFtUumyPOI+gqnsOelGwntQPlRK17cN96Zz+NRGaRurE/jS+WfSlEftQOyIyxPemnJ/GpvKPpxSiKi4WIRn/8AVQM9qnMf6UohI7c0XGVcE0uw4q0Y+cd6VYuKVwKnlnjilEZwKtiE9Kd5J7ii4FHYe9Hln3q8IPxpfIpXAoCLtThF7e9Xhb0phwPei4iiIj6Uoj9qvCIUvkZ6Ci4FDy6UQk9qvCDB6UojNK4yh5XJwKXyaveV7Gl8mi4FHyfzpDHkYrQMQPNIIuKLhYoiHHWneTgDAq55QNKIhzSuBS8k4o8k56Zq75YHQUBOx9KLgUvK9jQYuf5DFXCnNNKgUXAqeUaTy8e3tVsgDk4xUbbfUYouIg8vNIY+3Spi6gckVCZ4wSNwp3EHlgD3ppWmNdxDvUTXqdu9GoExXjrTW+nNVzejHHFRNenOccfSnZhcuEZ60w4A61T+1yEcJz9KYZp27GnZiuXcetGcd6qbbgnoRTmjlAJOaLBcsEgc5pC6496pF26E/Wk3e9FguWGlA4JqEylsnNMyaTNOwrilj+FG7jPfvTSaQnj6+9ADs0ZpN3PtmkyO1MB2aQnpTcignmgB2ccUhpM0mcUCFzx3FAIxTC3YUZoAfSZ5FNzx1pM88/XpQA8n8KQnHNNzSFsUAO+ooz7UzOaXNMQ4n6mmlvWgUd+uKQAaTvTvwFBx2oA9Xk0FSODg+tVJdGkj5DjHaugwx/i4pGjyMMai7Gck9rKhIIz9KjKsATjFdabWM9Rx6VG1lCR0GfpT5gucoCaXPFdDLpcDdB39KpyaR3Xd9KfMgMsE+/NKp5NWm064XPyZ+lQvbTIcmNvrTGCzMvRsY96sR386HhyRVIgrnIxz0IpQfX86AsbMOuSpjritKHxAMAMa5QnnNLu/KlYLI7mLWIZAORn2q0l3C/RxXnokYcBjU8d9MnRqLCsegBwehzQWri4dZlQ9ST6g1fi17puP6UWFY6TPFITmsyLWIn4YirK3cMgyHH40hFrNG+og4NBbnFMB5b8KTecUwtTCaAHls0nTmmZozzmgAJyPamk0pNMJ7UAIxqNjT6YaBjc08NnvUdLnFADXJ3cUqLu60EinKcDjrTAgmg49q53UodpORXUM9YOr/MhwOfWhCOWmVc8VVdMjAqQt+9IbNXoo7fALDOfetLjMqBSJAO+a6C2iyBxTYo7RWB2rx+NX47mJeijH0pNjHwwZHA4q7FbHjCnH0qBNQAHQ/gKkGpPwADx71DuBejtGxyhqdbYDggfnWYNRlzwoppvLg9Bj6UrMDZWBQPvL+dPAjH8YrC8+5YcEjPPSkBuG43MPpRYNTf3wj+Kk+0QDuawxDO3Ut+dKLKZsZJosBtG8tx6fiaadSt1HVfzzWWmmyHrxUy6U5OMGlZAWzq8I6EflUbawvbP5U1dIbPI/Cp10f1H6UaDsVjrDdArVGdUlbOEP4mtJdHGORUi6Ui9cD8aLoLGMb+4boo/Gk+03bnpj8K3Rp8C9StO+zWy/xii6Foc/uu26saPJuW6s3PvXQ4tFP3qQz2aelFx6GALGdupP509dMkPathtSsk67R9TULa5Zpzujx9aLsLlFdKbvUi6QfSpG8TWgyA449BmoJPFUIzgsfwxT1C5Ouj842mphpOO351kv4qwflVj+OKryeKJT0T82o1DU6EaXGOu0fjTxp8K9WSuSk8R3TdAoqs2vXrH74H4UrMdmdwLe3X+NfypMWi/xA1wTaveN1maojf3DZLTv/wB9U7Bys9AM9ov/AOumNqNnH/c/E1561w56ux+pphkJOTmiwcp3765Zp/HF+dV38S2i8BwT7CuIL800sTjiiw+U7J/FMP8ADuP4VVfxUCTtR/xrlsmjmnYORHRN4nlPCx/+PVWfxFdE8Ko/M1j4Y+tJg+9A+VGlJrl43SQAfSq7apdv1nb8Kq7D6UvlmgOVEj3c7n5pnP1aozK7A5Yn6ml8o5xS+XzRcdiPcfWk5xwalERNL5WetAEBz3oAyeOc1YEPX0pfK9qLgV8HFJtPvzVsQ56inGD2/KlcCns9jTih7VaEOccU7yKLgU/KNKIs9utXPIPXFPWDqMD86VwKPlH2pvl9K0fs/PAo+zc4xmi4WKAhyeR+dL5XoKv/AGfPanLAOmOtFx2KAhI6il8njGK0BAAenFL9n5HB/GlcLFAQ5PSneQRnitBYfl+7Q0WO3FK4WM4Re1OENXxEe4/Cn+ST25ouBneR7UogIrQWA56UrQ8ZouBQ+z//AKqcIKvCAgU4RY60rgZ5gz2pyw9O9X/KI6CjyhSuBS8gjpSeQ1XmUfgO1IdoHJFFwKghx9aQwYNWt8Q53D86Y1zCv8Y/OgCERGl8nnpzStewqPvVEdQhBJyPxo1FcmEIAo8rHvVV9XjFRNrAPRSaLMLo0TEOopvkgGss6s+OFNRtqc7fdU0+ViujXMYpCg7kVj/bLpj900hku5PUUcrC5s5QHG8VE80QIy4rJEN4x5Jpw0+5bglqOULmgbuBRgsPzqNtQgXoRVUaRKwB+apE0Nj97OKfKhcwNqcX1qJtUUE4U1aGiKvUDmpF0aMdQKLRFzGa2pknhDTGvpmHyqa2hpEaj7vHepF02MEHZn8KNBczObM1zJkgf/WpNl0w7k+tdUtgnZDxTxZf9MqLoLnJi0uW7kUf2ZM3Un611psm/ucfyo+xyddtPmC5yg0ZyRk80/8AsXHr711BsnbvikNj1LMMUucRzI0jB5NTJpsaY3YzW41rGOrj86Y0Nuv3pAaOYDJ+xQg5wKcIIl5x+laBNqvVqjMlvn5RmlcCoqJ2WknhTyWAHb0q2XQ/dX9Kjn5jJxgEUXA5i5AWUjFRZ469akuWzIe1QZ7Vqhsdn1ozTc80hPHYUAOzmkPBx+lJmkzzigQ4njn0pAeBTc0Z/nTAd2+tIW9qbmkzk0APJwKTNN3deaTNADiR1pO9Nzn3pe1AC5xRn2puPwpR0oEKTx14o70nQ0UAL1oA7UDilAzQAemKD6Ud+tL9KQB2FJ1zTjwPekxQB7asZ4Bpwjq2LVz0IpRavjnFZXAqCOoZmEak4rRMGOpFU7qKFh80nHemBlm4fdmr9tKJOCMmoilkvWTOPenJd2NuwO79aAuXvKUjkCmNaIx+6KgOu2adMVE3iW3HTHtRZhclfSIpByg/Kqsnh1W5RSPoaa/imMcgCq7+LBjggU0pBcbJ4dnByufxqlLpF1D1UED0NTt4rLZ+aqVx4jMgIySDVWkFyFkdGwwI+tMziqsuoiRs4JpovCfuoc/Sqsx3LwOOCaUNjvVOOaZzxC5/CrcUc7n/AFTZ96Qx6ueoJqVLqVD98475qJo3jHzjH1NMBB6GgDTi1aZPU/jV6LXDj5v1rn80ucDvSCx1ceqxScHANWVu4n6OK40McZB/WpVnkXGGP50CsdjvBGQQaTdXMRahKp6/rVqPVmGA1ArG9mo2NUI9TjbqR+dT/aomAG4UASlqaWpNwPQimk80ALuFIW/zmmlqaWxTAcW96N5A44qIk+9IW7UASO5I61mXg+U5/GrzPj2rOvXyjcjNAGJc2scjkjBPWs94jC4U5xRJcSJcEZ4qTz0cgsAT71Qyzbwk4rShtiw6VQi1GOMDAHHoKsLrgQcUmFmasdmccKcfSrCWB/u8VhnxBJ1AP4mmHX5zkAfrS1CzOlWwA6kAe5qYWcQ6so/GuQbXLk+gpjaxdN/y0x6Uh2Z26w2yjl1p4NovVhXBNqVw3Jmb8Kje8lYcysfxosFmegm7skPbNIdVsU7r+Jrzz7QxHLHmmmXPelYdj0E+ILJDwU+tQt4ptV6EfgtcH5hxigucZosFjtn8XQgcBufQVXfxhnO1H/OuQ3MTRzinYfKdM/i2f+GP82qBvFF23ACj3OawOeT6UoU/hRYOVGu3iG+Y53gfhULa1et1mI9cYqhtJ70COmOyLLajdOfmnk/76qNrmR/vSMfxqMJS+WT70DsBlJ55pN5JpfLPpS+WT2oCwzeeozS7mz+NSCI/SlEWKAIQz/pTvm9TU4ipfJI/rSuBW5PUmjaelWRD1p/knHNFxlMIRTgmetXfKz2zQICccc/Si4FTyuelHlkdqvCDHajyDRcCiIuM04R1f8ilEA9KLhYz/Kp3lcdK0PIB7Uqwg8Y6UrhYoCHigwelaQtxnGKd5I/Gi47Gb5OB07U4W59Ca0Ps+TkdKesPtSuFjO8jHalFvz0rR8kZxil8kii4Gf8AZ+KBBWisWaPKwaVwKIt+uacLcen0q6IhxUgiGOlFxGeLfngUogwavhADSMoxnIpXAqCAe9H2frkVayg4JFI00I6sOPei4EAg9RTzB83Sl+1wL/EKYdQhB4II+tGoXHi3xQ0BB6CoX1WEHrUD6wg6fpRZhcuCEA8/pS+WBWc2segqFtVkJ4U0WYrmv5YznFLtXqTWKb+4bojflTftN23QGnysLm5lV6kU1pI8/eFYn+mP2NO+y3j45NHKFzWNxCP4hSfbIRxnNZY026Y8lvxp66NOe7UcqC5cfUIV5x096ibVYwf8KaNBc9c1KmgYPIoshcxC+sKBwM1H/bLdlrQXQVA6Cpl0SMdRR7ocxjHVpW5CmmHULljwh/KuhGkRjtkipF0uIfwUroVzmGubx/4Tmoyl6/c12K6cuBiPj6VIuneifpRdCucYLK8bqx/CnDSrhurNzXbDT2/uU9dObjjFHMFzil0WVgMk/jUq6E3euzGnHvTv7OXv/OjmFc49dCHepV0OMYyK6z7HEvVhTvJtlPLClzBc5ZdFi/u/jipRpUYP3K6IvZp1cVGb2zX+IGi7FcxRpajpF+lSrpuDxHWi2q2q4wufoKibWF42RE59qNQuV1048DYKk/s1/QUp1S4I+WE0xry+f7seKNQuSDTj0wPxp39nqOrDiqZbUH56UeReN96Yr9DQBd+xRD7zim+XaIeXHFU/sUhHz3B/OojZQhuZjn60CL5lsU/iU4qJ7+yU8c1W8iyTguDTTJp8f8Q4osMmbVLfPCEn6VE2rddsBqBtR05Ow4qA69ZqONtFgLR1K5f7sPNRNc3z9EAqo/iSAfdxVR/E4z8ox9KfK+wjTYX0nVsVG1vdn70uPxrHk8RyE8E1Wk1+ZhwTVcrC5umxbnfMfzphs4Qfnl/WucfWLg9G4qFtRmY4L0+VgdQYbVB9/P400SWkZzn9a5VrqVv4j+dR+bKT945NHIwOrfUbdR8oFZ93qqyLtXH4VhF3xzn60iHLg0cg7jpWyaizzT5Acjio8E9qtAKT+AFJupMcUhU9qAHZz36UhOM4zSY/Ogg+lAAW60m7mkIx3pBTEO3UhNNyaXHr2pALk0tNpfxoAWijkmgfX86BgDnnFLyBR2zQeaBADRk0ZzxS44oAB60vOcZpOnSlHWkAuaMc4oAyKUdhQAufypMfWjrilxnNAz0pPFjg/eP51aj8YjHIPNcj51quNqqfbrSi8twDgIPwo5UB2f8Awlkb9uD7VMuqW11gFA2fbFcN/aajOMdM+lJ/bBHQn2pcvYR20mn29ypKB4ye4NZF1oN1nMNyGz2Y4rCXXZ1Pyuw9ealj8SXSMCefrRaSHYuPoOpqDuxt9jVRtNmjP72Ur7YNX4/FblQChHrirCa7BcLiYAg+oo55dUFkY/2KLOHnY+uOKd9lsx94sceprc8nTLocqgP+y2Khl0HT5RhJ5E/HNHOiuUywtgg+4Pxak+0WSfdjjA+lWZPCxbJhuwc/3hiqkvhi+T7oWQf7LVV0+orMX+0rdBhUQfRaRtYjHAH5CqMumXMP+st5B6nHBquYtp5BX60aBZmk2skcjOPrUZ1eTHC/rVEgAcAUmRRZDsWZNQmk601bybOeuKgznmjd+dGgWLqX0mRkmrSXueuM+lZIbn/69LuNFh2NsXKEdelSLMp6EH6GsDe3rT1mde59qVgsbyye9O39sisZbt1FSrenpSFY1BJjvT1ncfxnNZq3akVJ9oXH3hmgLGkl9IvO78KnXVWGNx4rIEgI60eZ70Csb6amjcGpPtaN/F+Fc35npThKR/EaYrHSCYNjBFBfIzXPreSLxnNTLqZAwTQFjYZuOtZ94x2HJOaVNSjfg4qK4nidTg9aBHOXeVmqvk9fWrV6AZc5zVbHrTLQbz6frTgxz1pFXIxTlXnpQMM49aAScYpwX15p6rx2oGMGacAakCU4RnNICHGetPCcdxUvl5p6xHtRcCuF+tOCZ+tWRD9aXyGFK4yv5fy5oEf51cEJ9OM077Oew5ouFioIz+VLsJz/AEq4IB6dvSn+Rxg0rhYoiPmneXxwKuiD6U8QA+uaLjsURFkU7yj6VoCDjPSnCHrx9aVwM8QketKIT+FaIhHYDpTljxg4FFwM8QU4Qe1aHlZOT/KnCH/OKVwM8W/tini2HFXfKz+HpTxDgfWi4ygIQB0pwhyP64q55YHNPCqByf1ouBT8oY6Uvk+w46VbPljHIpDJEAfmGaLgVhD7c+tOWA1J58I/iFH223GSCKLsQxYO+KeIO5H51G2pwKODUL6smOKNQuWxCM4PNOEIOfrWb/awHReKRtWfHCk0WYXNQwr2o8sCsc6lORwDTftl03RT1o5WFzaCr6j8aVjGvUjisMSXh5waTy7x+uafKFza86JTguKb9ohB+8KyBY3b9WIqRdLnPVmo5UK5oteQDvUb6nCKqro0h6k5qVdDz1zRZBcG1aIHion1cE8AEfSra6GvpUqaKg5wKPdFczDqznoppp1OduArfgK210iMDkVKulRjotF0FznDd3THO1qTzL1q6ldNQfw/pUq6ev8AzzOaV0FzkRDdsfvYpRp903ViPwrsl089kx+FPFgccKBRzCucaukTseWbNSLobnrmuyGnsew/KpBpzd6OYLnHroXTNTLoKdxXWjTx3NP+woByRS5hXOVXRIwc4FSrpEKj7tdL9mhXqwpdtsvVlouwuc+ulxKOF/SpF06PP3P0raMtov8AEKa19ar05pXYrmYunj/nnx9KkWw9E4q1/aMI6RmkOpf3Yj+VGoXIlsT/AHRUgsGJGR+lNOozn7sRH4Un2q8bpHijUCcWHHNOFio6kVU3XzHrigwXbfel/WgRc+yxL1YfnSeXbL1YVT+xyH709H2KIY3z8/WiwFsyWifxCmm9tF9DVUwWSn5pQfqaYZdMj6yKfxosBZOpW4+6mfwph1Vc/LF+lVG1TTIx95KgfxJpkR4K0cvkBonU5j92GmG8vX6R4rJk8X2aD5QD+FVZfGkY4VCfwp8r7CN4nUH74NN+z3j/AHpcfjXMSeNJDnahFU5PF90w4wB9aahIDsvsMp+/Oc/WkNjEB805/OuFl8TXr/x8VVfXL1/+Whp+zkB6EYLFP
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

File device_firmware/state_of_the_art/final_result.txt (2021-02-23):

{"device_id": 0, "timestamp": "2021-02-09 05:14:06", "advertiser": "", "image": "/9j/4AAQSkZJRgABAQAAAQABAAD/2wBDAAgGBgcGBQgHBwcJCQgKDBQNDAsLDBkSEw8UHRofHh0aHBwgJC4nICIsIxwcKDcpLDAxNDQ0Hyc5PTgyPC4zNDL/2wBDAQkJCQwLDBgNDRgyIRwhMjIyMjIyMjIyMjIyMjIyMjIyMjIyMjIyMjIyMjIyMjIyMjIyMjIyMjIyMjIyMjIyMjL/wAARCALQBQADASIAAhEBAxEB/8QAHwAAAQUBAQEBAQEAAAAAAAAAAAECAwQFBgcICQoL/8QAtRAAAgEDAwIEAwUFBAQAAAF9AQIDAAQRBRIhMUEGE1FhByJxFDKBkaEII0KxwRVS0fAkM2JyggkKFhcYGRolJicoKSo0NTY3ODk6Q0RFRkdISUpTVFVWV1hZWmNkZWZnaGlqc3R1dnd4eXqDhIWGh4iJipKTlJWWl5iZmqKjpKWmp6ipqrKztLW2t7i5usLDxMXGx8jJytLT1NXW19jZ2uHi4+Tl5ufo6erx8vP09fb3+Pn6/8QAHwEAAwEBAQEBAQEBAQAAAAAAAAECAwQFBgcICQoL/8QAtREAAgECBAQDBAcFBAQAAQJ3AAECAxEEBSExBhJBUQdhcRMiMoEIFEKRobHBCSMzUvAVYnLRChYkNOEl8RcYGRomJygpKjU2Nzg5OkNERUZHSElKU1RVVldYWVpjZGVmZ2hpanN0dXZ3eHl6goOEhYaHiImKkpOUlZaXmJmaoqOkpaanqKmqsrO0tba3uLm6wsPExcbHyMnK0tPU1dbX2Nna4uPk5ebn6Onq8vP09fb3+Pn6/9oADAMBAAIRAxEAPwDtxz7+9NPWnUneqMg9qKUUUDENIBzSmkx60gFo7UClI4oAibr0qdelRY+apwOlMQtGKKMcUAFL0xRSd6YC9qSijrQAtJS0YoABxQDkjpS96AAevNIB44pcU0Ht3p1IYDHajp3pM0tABikpc8U3k0DEOaMZxTwKQikAgFKaM80EUwEHTFBpaQ0hjc04U2lH60AB4oIpTSHmgAHHWg80g606gBpGaBS45oxQAUlL2o70AJS96TvS0AHakpaMUAIKKWigA/nRR9aWgApVFJT1GOaAFNJS0mPWgA60fyoxSmgBtFLRTASgUUEUAFJS0UAJQP1opcZ70AJRRij6UAFFFFAAaSiloABRRRQAlFLiigBKWjFFABRiiigAoopcUAJRS9KSgQUGlpKBh0oopaBCUe1FFACUUtFACUUv5UhoAKKKKAEpaMUUAJRS0UAJS9e9GKPSgBKKOtFAB2oz3ooxQAUlLijFMBBzS0lLQIOlFFFABQPpRiloAKKO+aMUAAoopaACkopaAEo7UtFACYopaKBBRRSgUAJQKWkpgL0pDS0CgAoBo70UAFAoxRigApKWigQUd+KO+KB/OgAIoxz1o60UAFFA60d6AEpelFFMBPalpMUtACfjR+lLSUCDvRilH60HigAxSGl7UlAB3oPHvRS0AJj8aSl/zijvQIKKKD0oEFFFHamAZ5xSUtJ2yaBFbtTRmnE8cU1ag2FyelLRilxQA00ClNApALR2oxkUh4BoAROXGamA4qGPls/lUw70wFFFHeigQUUUUwCj8aKX1oATg0tFHSgA5pwAptOWkAvelpDSrSGGKXFH86O9AB1pOhp1NNAxaSlFIaAGk/NTu1MxTxQAU1gadSYpANxS98YoPpQKBhjim07FBFAAKXrSY70uKAEoxS/hSUAGKKPxpaAG4paKKAEpaKKADFGKKOtABSYp1J3oAKevSm4qQDigBKKXpRQAlFFFACUUUtMBKKWkoAKKKKAEoGcdaOtGKACiiigApMUopaAG4opaKAEopaKAEopaKAEpcUvvSdqAAelFFFABRRRQAdaOaXHekoEFGKKKBhRS96Q96AAijFFFAgooxRQAlJS0UAFGKKBQAlLRRQAUUUUAJ1opeaKAEpKWjFACUUuKKACkpaKYCUUtFAgpMUtFABRS9qMdqADtRR0ooAKKWjtQAlGKXvRQAlLRQKAEpTQaKAEpaKKBB2o70UfjTAKKOlH40AFFFLzQAgPWil70UAIelA4paM8UCCkFH+eaUUAFJSnpSY4oAXpRRRQAmKX+dHejFACUUuKO1MBM0Zoz+dFAgxRS0nagAzRRSGgBaO9FHSgQUlLRQAnSlxSfSlpgHQ4ooooEJRyKXFJ60CKp+7k0AUPwaUZxWZsFAopR05NADWNNDY96cRk9aXbxQABwfWkbp1oK0w5AoAkiHBzUtRxj5alFMBKKX+dFMQUYoo5oAKP880vWk/GgAoNL0oxQAnepF9fypmKkX0pDFx60Cl7UdqQCUUtIOtAwPpR+lLSEUAHemnpS01qAFAz06UuKauadQAhopcUzvSGKcGkHWndqMc0AGKKWkoASil/SkPAoAM0GmjOaUigBM0tGMUvQUAJ2pM807vSY/OgAopRRigAFFGKWgBKKXFFACj2p9NUU78aAEoopcUAJRRRTASgUvek6UAIfagU6koAT6UtH40UAJRS0d6AExRS4pKACilpO9ABSd6dR3oASilpMUAJRSil7UAIKMUuKKAEFFLiigBKPxpcUfhQAlFHWloASilpKACiiigAoopaBCUUUpoGNxRil60UCExRRS0AJR70tJQAlFLiigBDR3pTxSUAHaiiigBKWiigBKKXvRTASilo60CEpaO1FABRS4xSY5oAXtRSCloAKO1FHWgBaQ9aXv3pKACilpO9AC9qSloIoAKSlFGKYCUooooEGKPQ0UdaADNFHSjH/AOqgAooo60AHeiilxQIKSlooAPSkpRRQAlL+tGKMUAJ3opaSmAUGg0UAJR1zS0Y9KBB1pDxS0etACe1H0paSgA60vWkoxQIKX0pKP50AFFAopgHWj3xS0daBCUdKKXtQIqH71LTeMmnVmbCfjRS9aKAEA5pxpo96XNABTCOcU+mn7/TgUASp90fyp386RelLTAMUUtH1oEJS0e1FMAxRS9KTFAB0petJ2pcUAFOGaQdRUmKQw7UUhHFKKQxDS0dKTNACn6UUe9HagBMYoxS8UlADcY4paXNITzSGLSY/CkBzSnmgBCaBRigAAUALSDmg0goAXFFFIc49qADFLimjNONACYooooAOlGKTNLnigANFHQU3qaAH0UmKXmgBKWil/GgBy0poUUpoASijFGPamAUlLR3oAbilooxQAUUUtADTS0UUAJRS0UAJRS9qTvQAUUUUAHSilpKACiiigAFFHeloASjFLRQAlFLQaAEFFGMUuKBCUUtJQMMUUtJigBKWl4ooATFFFLQAhoxRRigBKKX86MUAJj1pKWkNABRSUtAgoo60UAFFFFAB2opcUlABSUtHtQAmKKXrSUwCjFLR70AJRS0UCDrRRRQAUUtJQAUvaijtQACiil9qAEo7UUtABRSUtACY470UtGKYBRRR+FAgxiigelFABRRRQAUUfrRQAUUe9Lj2oEJRRRQAdqKKWgBMUAd6WkoAKMUYo75pgFJzS4ozSATFA49aXFGKYAab706igQn+c0mKXvR1oAKKD0ooAKMdqD1paBCUGgc0fjTAKO1BFHSgQUUDvRQIqE4Oc0A8UnJ604qKzNgoPFJikPPFADh0paQcClzQAHgUxfv4pWNEXLE0ATKOlLSCnUxCCj6UUUABo7UtHFMAxR70DrS0AJigUtFACrwaeDTVFKTjpSGOopOop1IYw0g607FGOeKADtSZpcUmKACj680o780EUgG9aMUd6AcigYAUtHFGcUAJmj+VIaQcZoAdikIpc0lABRwTQaQdaAFxQRniil7UAJjrRzS9qTFABigCloNACUYHag0UAGKXFFFACYpwGKQUo60APWl+lAHFFACc0UUUwCkzilxSUAFGKKPwoAKMUUUAJSgYo9qWgBKSlooASjFLRQAmKKWigBKMUUtACUmKWj2oAKDS0negAopTSYoAKOlLRQISgUtFACYopaSgYfjRS4pOlAC0mOKWigBKKKWgBKKOlHFABSUGkJoAQ0lBPNNzQA7NLTM04UALS5pMUtAgooooAKOlFFACd6KWigBBR2oopgFFFLQAUlLR2oEJS0GigAowaKWgBKWiigAopcUhoASloo9s0AFFFFABiiilpgJRRS0CExmil5ooAKKO9HWgBKXFHeigBKWiigQUUUUAJS0UdKADGKBR2zRQAnSg9BS0UwE6UdaKXpQAlFL9KbzQAtFAooEFJS8ZooAMUfhRRQAUCijvQIQijmlNJTAKAKWigQe1Jil70ZoEU06+lSUxBgCn4rM2EpjetSGmHrQAdadigAU7gCgCN+nSliHHSkc80+MYX3pgPoFL2o9aBBiiiigAAooopgLjNAzRRQAUYope9Ax6jjBoIpV6c0tIBNuOKKXNFIYUgpfpRmgAppz604UhoAYMmn4o6Uf1pAMagZpT+tFAxKQ9fendqQDigAHSkIpQPpTsUAMzSkcilxS0ANA4oxS0UAGKBR1oxQAlFLRQAmOaTrS0H2oAKKKKACiiloGFKBSU5etAD+lJS0nTpQIKKPajtTAKQ0uKKAEoxRS0AJRR0ooAKKMUUAFJj8qU0UAIeKPelNFABik7UtFACUUtFACUYpe9FACUYoooAM0d6KXFACUd6WjvQAUnNLxRQISj9KUUlACc0oo6UUDDFGKKWgBKOlL680lAB9aQ0uaSgBD0pjHFOJxUDv1xQApam7qjLc8Um6gCcGng1XVuamU5xQBKKXpSdqWgAooooEJ3oHNLRQAlFLSGgANFFLQAlFFFMAFFFFAgopaKADFFFFAB/KiiloAQUUtFABRRRQAlFLRQAlL2oooAMUUUUxBR0FFFABRRRQAUUUUAFHfmiigAopaTH0oEFFFGKAClzSUUAFBpaTqKADpRRRQAYoNFFMBKOaU0CgBCDzS/qKDSUCAH0opaKAEpe9Jmjt1oAKPrRS0xCYopR0pKBADSHrTs0lAisvTNPpoGDxTu1Zm4hzio8ZantwKQc0CFA/GgnilxxQRQBC/Wp16D+tQnlwKsDpTAO3vRRS0CEFFLRQAgpaDRTAOaKKWgBKUUfnSgelAxw5p1IPp0p2KkYnTNFBHFHSgAoPPalpDQAgozSGjFACE9KUdKCKUDikAmOaQin0mPrQMb2oAp2KMUAIKKXGaOlADcd6WiigAoooIoAQ0DpRRmgA4oNFFACUvvRSGkMM0UgFOoAKKKKYBinrTRT1H5UALRS0GgQlFFFMApMUfSl70AJR+NHaj+dABRQaKAENL9KBS+1ACdKTmlopAJ9KWijtzQAlFGKWmAhoo70tACdaKOlGKADFFFKBQAmKKWigBO3rR3paKAEoxS0UAJ3oxS0dqAENFLSYoAKKWkoASjFL70uMUANpOgpTTHOBQBHK+O/NVHkpJ58ZweaptIT0pNjSLJk5pQ/vVPc1Kk2Dg0rjL6nmrCHIqij5/GrcJ96YiyKX60g6UopiCjpRS0AJRS0lAgooooAKSlo70AFJS0UwCkpRmjFACYpcUtJQIO4paKKAEpaKMUAGKKKKACgUYxRQAdqKKWgBDRjNKKKBCUUtLQA2ilopgFJTqSgAx+NFFFABSUtFACUtFFAB06UUUUAIaMUuKKBCdKMUuKSgAxQaM0daACjFLSUwDvRQenSjFACUvNHejPFAgox+FHtRQAlFLRQAlGKXtxRTEHak70tFAhKKXtR296BFcZpRzUYDAUBmH/ANcVmbDm6UDpTSc9eKeB7UAHNBOBzS1Gxz+FACJ80nSp6hi5Y1PTAMUd6KSmIXtRRSigYlLjiig0AJ05xS/jSUvagAp69qZinrxk0gH0UDrRSGFIQSKU/pSZpAAGKdTaAc0ALSUp4pM0AFFHeloASj6UtJQAUn1paDQMQ0UY5oxQAUlKaOlACfhS0UUANJpp5pStKKQABTe9OpNvNAxR0oIzRQeKAExThR1ooAKKKBxTAUU9elMHFSAfnQIKSnYFJTAOaO3+NFFABSdqWk6UAHeiij6igAopaSgAoo78UdPxoAKKKPpQAdqTGe9FFABS0YooASjmijoaADHegjiil60AIKPal70UAGOKMUfjRQAnNH1FLSCgAopcUUAJR/OjqKMUAGKKKX3oAQ0YpaO1ACUhpf50UANNVLqXaMDrVmRtik9fQVSI3sSeTSGijJG0nJz+FRsjL2rSK4FMaMEdKQzPU54NOePK5xzUkkWG46inIMikBDEzL8p/CtG3OTVB12/NxV2z+bJpoGXgKWgUtUSJS0UYoEGKSndqKAG4opaKAEpaTHNLQAUmKWigApKWimAUYoxRQAYox6UUUCCiiloASl7UUd6AA8GkpT0ooAMUYoooAKKWigBKKKKBBS0UUAJ2pTRRTASlopKAD9aKPc0GgAooooAKKDRQAZoo9KAKBBSdvSlo60AJSj0o70UAFFHU9aKYBSEUvWj+lACYpaKSgQfhRS9aTFABR9aDzRQIKKKKACgUUtMQlB6UvQ0lAiDFKVHpR9aXFZmxEevSn4IFMPB96XzBigBT9KY/Ap4ZaY/IoAdAOM1LimRjC08UwFNJSmj+VMAooo7UAFFGKKADFFLQKAEqRRxxTcfpUi/dpMAHFIetOJpMdzSGJzijFB/SlzSATFAHajH504daAENNHFP7UmKACijNFABSUh+lHWgYv4UmfxoYUgoAXNLRijt1oATpzSZNLmigA/nRS4ooAaTSDmlI4oxQAtIaXpSe9IAopQKO9AwpKU0UAGKSlooAUDmpOlNUU+mISilooASijFLTGJ0oxxS4pKBCYopaTpQAUH0paTFACUtGKKACijoOKPYUAJ+VFLRQAgopcUUDEopaKBCUClooAT8KMUtHegBKWjvRigApKdTcUAFFKaKAExQaO9FABRilxRQAmPrRS0UAJ1pKWjtQBXmyWx6VFtqZwSxpuOakZHtpCtSkU0igZUmTnNJDGD2qx
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

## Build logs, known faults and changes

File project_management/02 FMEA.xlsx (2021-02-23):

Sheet: Failure Modes
Requirement | Failure Mode
 | Too Much | Too Little | Intermittent | None At All | Unintended

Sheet: FMEA Table
Requirement | Failure Mode | Severity (1-5) | Likelihood (1-5) | Detectability (1-5) | RPN (1-125) | Mitigation Plan

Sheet: Appendix A UX Chart
Appendix A: Product UX Chart
Environment How might the environment affect the product? How might the product affect the environment? | Atmospheric conditions | Attitude/ pressure
 |  | Humidity
 |  | Gas composition
 |  | Pollution
 |  | Air temperature
 | Acoustics | Noise
 |  | Vibrations
 | Power supply type | Mains frequency
 |  | Plug type
 |  | Accessibility to live parts
 |  | Mains voltage & current
 | Radiation | Electromagnetic fields (EMI)
 |  | Sunlight (UV)
 |  | Visible light
 |  | Thermal radiation (infrared)
 | Operation environments | Building type
 |  | Country regulations
 |  | Indoor or outdoor
 | Contact surfaces | Dry/ damp
 |  | Slippery/ grippy
 |  | Smooth/ bumpy
 |  | Hard/ soft
 |  | Abrasive surface
 |  | Contact temperature
 | Transportation environment | Temperature
 |  | Humidity
 |  | Attitude/ pressure
 | Storage environment | Temperature
 |  | Humidity
 |  | Attitude/ pressure
Materials What materials might come into contact with the product? What materials can the product emit? | Intended Interactions | User interface e.g. buttons
 |  | Pick and place
 |  | Fastening
 |  | Cleaning product
 |  | Product maintenance
 | Material subjects | Animals
 |  | Human
 |  | Food
 |  | Synthetic
 |  | Air-borne
 |  | Water-borne
 | Hazardous materials | Abrasive surfaces
 |  | Volatile/ flammable
 |  | Corrosive
 | Unintended interactions | Ingress
 |  | Contaminants
 |  | Unexpected cleaning products
 |  | Unexpected replacement parts
 | Material failures | Freezing/ jamming
 |  | Change in color/ translucency
 |  | Material wear/ thinning
 |  | Cracking/ fracturing
 |  | Clogging
 |  | Water absorption
 | Emissions | Smells
 |  | Liquid
 |  | Dust and debris
 | Material properties | Case durability
 |  | Rigidity/ flexibility
 |  | Waterproof/ absorbent
 |  | Magnetic
 |  | Static
 |  | Conductive/ insulating
User Interaction How is the product supposed to be used? What are the possible uses of the product? | Transport | Handling in freight
 |  | Hand-carry the product
 | Before use | Packaging
 |  | Unboxing
 |  | Installing product
 | During use | Principal use
 |  | Connection with Internet/ other device(s)
 |  | Foreseeable misuse
 |  | Abuse/ abnormal use
 |  | Use alongside other product(s)
 |  | Hacks
 | Maintenance | Cleaning
 |  | Replace parts/ repair
 |  | System reboot
 | After use | Disposal
 |  | Recycle components
 |  | Reuse components
 | Power use | Power continuously/ short runtime
 |  | Mains/ battery powered
User Profile How might the product accommodate people's wants and needs? How might the product be interpreted/ misinterpreted? | Active users | Gender
 |  | Age
 |  | Relationship status
 | Individual factors | Hand size
 |  | Left/ right handedness
 |  | Strength
 |  | Body weight
 |  | Height
 | Special needs | Elderly
 |  | Infants
 |  | Handicapped
 | Cultural beliefs | Religion
 |  | Traditional customs
 |  | Conservativeness/ progressiveness
 |  | Crowd behavior
 | Preferences & expectations | Product’s quality feel perception
 |  | Audio-visual cues
 |  | Product capability e.g. works well, hassle-free
 |  | Positive/ negative associations
 |  | Brand perception e.g. luxury? durable? good service?
 | Understanding | Technical knowledge
 |  | Industry knowledge
 | Unexpected interactions | Mistakes
 |  | Instructions ignored
 |  | Improvisation
 |  | Subjected to impact
 |  | Poor treatment
 |  | Product causes accident
 | Servicing | Professional
 |  | Product owner

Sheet: Appendix B FMEA Ranking
Appendix B: FMEA Ranking Description
Severity | Hazardous failure with little to no warning | 5
 | Complete tool failure that leads to the tool being scrapped | 4
 | Component failure that leads to tool inoperability and may be rebuilt with replacement parts | 3
 | Defect that may be customer facing, but won't lead to tool inoperability | 2
 | No or negligible defects | 1
Occurrence | Greater than 75% probability of occurring | 5
 | Between 30-75% probability of occurring | 4
 | Between 10-30% probability of occurring | 3
 | Between 2-10% probability of occurring | 2
 | Not expected to occure more than 1-2% of the time | 1
Detectability | Not able to detect | 5
 | Not able to detect 50% of the time with current controls | 4
 | Able to detect 80% of the time with current controls | 3
 | Able to detect 97% of the time with current controls | 2
 | Able to detect in all instances with current controls | 1

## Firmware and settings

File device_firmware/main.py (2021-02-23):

import json, datetime, base64, requests, time, ast
#import numpy as np
from PIL import Image
from pi_stream import cam_init, get_frame_from_stream

config = None
with open('/home/pi/Desktop/device_firmware/config.json') as f:
    config = json.load(f)
ID = config["id"]
URL_UPLOAD = config["url_analytics"]
IMAGE_DUMP = config["current_image"]
VIDEO_DUMP = config["current_ad"]

def package_img():
    with open(IMAGE_DUMP, "rb") as img_file:
        tmp_img = base64.b64encode(img_file.read())
        tmp_img = tmp_img.decode('utf-8')
    return tmp_img

def send_report(image_arg, adv_arg):
    t = datetime.datetime.utcnow()
    tmp_time = t.strftime("%Y-%m-%d %H:%M:%S")
    
    body = {"device_id": ID,
            "timestamp": tmp_time,
            "advertiser": adv_arg,
            "image": image_arg}
    head = {'content-type': 'application/json'}
    

    r = requests.post(URL_UPLOAD, data=json.dumps(body), headers=head)
    print("====> main: ", r.status_code)

    """
    with open('final_result.txt','w') as f:
        f.write('\n')
        json.dump(body,f)
    """
    
def main():
    print("Executing main.py ...")
    camera = cam_init()
    while True:
            img_ori = get_frame_from_stream(camera)
            img_ori.save(IMAGE_DUMP)
            img_packaged = package_img()
            
            with open(VIDEO_DUMP, 'r') as ad_file:
                ad_ori = ad_file.read()
                ad_ori = ast.literal_eval(ad_ori)
                ad = ad_ori["adv_content"]
                
            send_report(img_packaged, ad)

if __name__ == "__main__":
    main()

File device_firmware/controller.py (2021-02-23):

import os
import time
import json
import psutil 
import requests 
from datetime import datetime
from led import led_persist, led_off, blink, fade
from subprocess import PIPE, Popen
        
config = None
with open('/home/pi/Desktop/device_firmware/config.json') as f:
    config = json.load(f)
ID = config["id"]
URL_ALIVE = config["url_ctrl"]
PROCESS = ["/home/pi/Desktop/device_firmware/main.py", "/home/pi/Desktop/device_firmware/video_tracker.py"]


ai_alive = PROCESS[0]
video_alive =  PROCESS[1]

def get_cpu_status():
    process = Popen(['vcgencmd', 'measure_temp'], stdout=PIPE)
    output, _error = process.communicate()
    output = output.decode()
    cpu_temperature = float(output[output.index('=') + 1:output.rindex("'")])
    cpu_usage = psutil.cpu_percent()
    return cpu_temperature, cpu_usage
    
def get_memory_status():
    ram = psutil.virtual_memory()
    ram_total = ram.total / 2**20   #in MB
    #ram_used = ram.used / 2**20
    #ram_free = ram.free / 2**20
    ram_percent_used = ram.percent
    return ram_percent_used


def check_python_run():
    """[summary]

    Returns:
        [type]: [description]
    """    

    program_result = {}
    for i in PROCESS: 
        program_result[i] = False

    for proc in psutil.process_iter():    
        try:
            proc_identity = proc.as_dict()
            if proc_identity['cmdline'][1] in PROCESS: 
                program_result[proc_identity['cmdline'][1]] = True

        except:
            pass
    return program_result


def send_report(program_result, cpu_temp, cpu_used, ram_percent_used): 
    """[summary]

    Args:
        program_result ([type]): [description]
    """    
    tmp_time = datetime.utcnow().strftime('%Y-%m-%d %H:%M:%S')
    body = {"device_id": ID,
            "timestamp": tmp_time,
            "ai_alive": int(program_result[ai_alive]),
            "video_player_alive": int(program_result[video_alive]),
            "cpu_usage" : float(cpu_used),
            "memory_usage" : float(ram_percent_used),
            "temperature" : float(cpu_temp)}
    
    head = {'content-type': 'application/json'}
    
    try: 
        r = requests.post(URL_ALIVE, data=json.dumps(body), headers = head)
        print ("===> monitoring: ", r.status_code)
        
    except Exception as e: 
        print ("-->> " , e)
        
def led_machine(state, dur):
    if state == 1:
        led_off()
        led_persist()
    elif state == 2:
        led_off()
        time.sleep(0.1)
        for i in range(dur):
            blink()
    elif state == 3:
        led_off()
        time.sleep(0.1)
        for i in range(dur):
            fade()
    else:
        led_off()
        
def main(): 

    print("Executing controller.py ...")
    while True:  
        duration = 10 
        led_state = 0
        program_result = check_python_run()
        cpu_temperature, cpu_usage = get_cpu_status()
        ram_percent_used = get_memory_status()
        
        send_report(program_result, cpu_temperature, cpu_usage, ram_percent_used)
        #print("main.py: ", program_result[ai_alive] ,", video_tracker.py: ",program_result[video_alive])

        if program_result[ai_alive] == False or program_result[video_alive] == False:
            #os.system("./rerun.sh")
            #print("=======")
            led_state = 3
            
        elif program_result[ai_alive] and program_result[video_alive]:
            led_state = 1
            
        led_machine(led_state, duration)
        #time.sleep(duration)
        
if __name__ == "__main__":
    main()

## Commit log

2021-02-23 adding device_frimware directory
2021-02-23 commit device_fw files
2021-02-23 project management documentation
    [02 FMEA.xlsx, 03 Disruption Handling Database.xlsx, A.stl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]
2021-02-23 device firmware for Mera
2021-02-23 general operational documentations
    [02 FMEA [Template].xlsx, 30mm_axial_fan.step, Bill of Materials 2020.xlsx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]
